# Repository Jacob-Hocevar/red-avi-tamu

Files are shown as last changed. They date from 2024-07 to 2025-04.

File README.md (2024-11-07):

# TAMU RED Avionics and Controls

This repository is home to the code and documentation for the Avionics and Controls subteam of the Texas A&M University Rocket Engine Design (<a href="https://www.tamured.space/">TAMU RED</a>) team.

## Organization

This repository is organized at the highest level by campaign. The current testing campaign is Elysium and all current code-related projects are found within. All previous campaigns are located within the Archive directory.

This repository is managed by <a href="https://github.com/Jacob-Hocevar">Jacob Hocevar</a>.

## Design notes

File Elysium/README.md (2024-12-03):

# Elysium
## Elysium GUI
The Elysium Graphical User Interface is the primary way that the system is controlled. It handels the inputs of the operator, automated control sequences, as well as the live display, graphing, and storage of data. It is programmed in C++ with Qt. For information on how to run and recompile (as needed), see the README.md in that directory.

## Real_Teensy
This directory contains the sketch(es) used by the Teensy to interpret the signals from the GUI, directly send the signals to actuate the valves, and read/transmit data from the sensors. Additionally, the system will handle an abort if there is a communications failure.

## Virtual_Teensy
This directory contains the code for a simulated version of the Teensy which is used to test the GUI. It recognizes and prints out any commands it recieves, and allows a user to control the data that it outputs to the GUI. For information on how to run and recompile (as needed), see the README.md in that directory.

Additionally, it will be configured to connect to another real Teensy to allow for Hardware In-the-Loop (HIL) testing.

## Data Formatting
For Elysium, all data will be transferred in `key:value` pairs. These pairs can be chained together in a comma separated string `"key1:val1,key2:val2,key3:val3\r\n"`, which terminates the carriage return (`'\r'`) and newline (`'\n'`) characters (the standard ending protocol for serial communication).The three goals are standardization, ease of maintainence/extension, and redundancy.

Standardization is both across programs and across subteams. We shall use the IDs of Sensors and Valves from the cross-team P&ID as the `key` terms, and the relevant data as the `value` terms. This will eliminate confusion between groups that were experienced in the WTS campaign, when one team was using `P1` and `P2`, and the other was using `PA` and `PB`.

This makes maintainence easier because it allows sensors and valves to be universally configured with a single, critical value. Similarly, if more valves or sensors are added, they can be added to the system with the same, single value.

This allows for some redundancy in the data transmission. If one value or part of a value fails to send correctly, the rest of the data in that batch (because of the keys), can still be readily and accurately identified by the receiver.

### Comparison to Older Design
Compare to the simpler system used during the WTS campaign: Comma separated values where the position dictates which property it corresponds to. First, the order of the properties had to be explicitly coordinated between the Teensy group and the GUI group and was not in reference to an existing, agreed upon document (such as the P&ID). Second, if a new sensor was added, both sides had to again determine where in the sequence to put the new value and manually hard-code it. Finally, if one value fails to send, all the following values (in that batch) are shifted and thus misread by the system.

### Example
Suppose the P&ID has three Pressure Transduces (P1-P3), two Thermocouples (T1 and T2) and one accelerometer (A1), which reads accelerations in three directions. The Teensy also outputs the local time with key `t`. Thus, it should output something like:

`"t:6545450000,P1:685.5422001,P2:14.78512405,P3:500.12124541,T1:7.2301502,T2:312.128575954,A1x:0.784213850,A1y:0.34517850652,A1z:2.0006781249\r\n"`

The order of the pairs does not matter, so something like the following is also acceptable, though less readable for debugging:

`"P3:500.12124541,A1x:0.784213850,P1:685.5422001,T2:312.128575954,A1z:2.0006781249,P2:14.78512405,T1:7.2301502,t:6545450000,A1y:0.34517850652\r\n"`

### Valve Example
For the valves, the solution is nearly identical, except that each command is always sent on its own line (no comma separated strings). Additionally, the value `0` always denotes a closed valve or close operation, and the value `1` always denotes an open valve or operation. For any extra electrical components (such as the ignition system), `0` will correspond to no power and `1` will correspond to providing power.

Consider a system with four normally closed solenoid valves (NCS1-NCS4) and two linearly-actuated ball valves (LA-BV 1 and LA-BV 2), and an igniter (IG1).

The signals to close all solenoids, open all ball valves and power igniter #1 would be given by:

`"NCS1:0\r\n"`
`"NCS2:0\r\n"`
`"NCS3:0\r\n"`
`"NCS4:0\r\n"`
`"LA-BV 1:1\r\n"`
`"LA-BV 2:1\r\n"`
`"IG1:1\r\n"`

Spaces in the IDs do not affect anything in either system. Again, these could be given in any order.

## Known Issues
There are a couple issues which have evaded all attempts to remove, but have simple methods to circumvent.

### GUI Freezes when connecting to Teensy
Identify: This typically results in the GUI freezing for several seconds, then expanding to full size, but not detecting any data inbound. It also will freeze upon shutdown or disconnect.

Cause: The connection to the Teensy is really sensitive with repeated connections and disconnections, especially with the WSL forwarding.

Solution: Unplug/replug the Teensy, and immediately attach it to WSL and attempt the connection again.<br>
A similar fix is to detach from WSL, and open the serial monitor in the Arduino IDE. Try opening and closing the serial monitor menu, and it should alternate between correct functionality, and a blank screen. When it is on a blank screen, close it, attach to WSL and attempt the connection again.

### GUI Connects, but the Teensy stays in the aborted state
Identify: GUI immediately "connects", but all data fields remain blank and the terminal is filled with `Not enough data: Aborted` and `Not enough data: New Input= nop`.

Cause: The connection to the Teensy is really sensitive and the first data sent over the connection often is lost/corrupted (buffer overriden?). This only occurs the first time after the Teensy is restarted.

Solution: Close the GUI and relaunch it. Not totally sure why, but it only ever happens the first time.

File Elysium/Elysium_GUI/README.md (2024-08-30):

# How to start the GUI

First navigate so that your active directory is `Elysium_GUI`.

If you have made no changes/it is already compiled, simply run `sudo ./Elysium_GUI`.

If you have just changed a couple files, but not added significant includes or new files:
1. `make` to compile.
2. `sudo ./Elysium_GUI` to run.

If you have made signficant changes (new files or substantive includes):
1. `qmake -project` to (re)create the project file.
2. Update the project file:

    A. Set `INCLUDEPATH = ./Headers` so it can locate the header files.

    To let the makefile/compiler know where to find core includes:

    B. Add a line reading `QT += widgets` for QApplication and QMainWindow, among others.

    C. Add a line reading `QT += gui` for QPixmap.

    D. Add a line reading `QT += core` for the namespace (alignment flags, among others).

    E. Add a line reading `QT += serialport` for the serial connections.

    [comment]: # (Update Here if new lines become necessary)

3. `qmake Elysium_GUI.pro` to generate a makefile from the project file.
4. `make` to compile (this is where errors will show up with improper code).
5. `sudo ./Elysium_GUI` to run.

## Setup
Use a unix-like enviornment and install the proper libraries.

In my case, the command is `sudo apt install make` to install `make`.

You will need the `g++` compiler and the access to the commands `make` and `qmake` (via `qtchooser` library), and `qtdeclarative5-dev`.

Additionally, for the serial comunication, I installed `libqt5serialport5-dev`, and for the live graphs, I installed `libqt5charts5-dev`.

## To connect to the Teensy via WSL
1. Install `usbipd-win` via the .msi file for the latest release https://github.com/dorssel/usbipd-win/releases.
2. Open Windows Powershell as administrator and execute `usbipd list`.
3. Identify which device corresponds to the Teensy (the description may not list it, so confirm the COM number via the Arduino IDE or any other method) and remember the bus ID.
4. Execute `usbipd bind --busid ID` (with the previously found `ID`). Verify that it is shared with `usbipd list`, if desired.
5. Execute `usbipd attach --wsl --busid ID` (with the previously found `ID`). Verify that it is attached with `usbipd list`, if desired.
6. A more precise way to verify is to open WSL terminal and execute `lsusb`, which should list the attached port.

To detach, either remove the device physically or execute `usbipd detach --busid ID` (with the previously found `ID`).

Every time the device is disconnected or the PC restarts, you will have to repeat step 5 (although, it would be wise to recheck the list to confirm the `ID`).

## Additional Note
The `sudo` keyword is needed for running the executable in order to access the serial ports. You will recieve a `PermissionError` without it. I am not certain why this is, but I think the `/dev/` directory (which is how ports are treated in WSL) is considered protected.

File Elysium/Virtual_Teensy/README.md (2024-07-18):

# How to use the Virtual Teensy
## Setup

Install the socat module with `sudo apt-get install socat`.

## Usage

Open two WSL terminals. In first, it does not matter what directory is open.

Execute `sudo socat -d -d pty,raw,echo=0,b115200,link="/dev/Test_GUI" pty,raw,echo=0,b115200,link="/dev/Virtual_Teensy"`. This will generate a pair of `/dev/pts/X` serial ports with arbitrary values `X` (typically, 0, 1, or 2, but can vary based on system activity), which are linked to the fixed names `/dev/Test_GUI` and `/dev/Virtual_Teensy`. This command needs to remain active as long as you need to test the GUI/Virtual Teensy.

In the second terminal, navigate so that your active directory is `Virtual_Teensy`.

First navigate so that your active directory is `Virtual Teensy`. Execute `make` any time you update a source file. To run the Virtual Teensy, execute `sudo ./Virtual_Teensy`.

## Additional Testing
If the Virtual Teensy is not working (or for some other reason you want to check that the virtual ports are working), you can manually send information to and recieve from the pair of ports via the following commands.

`sudo bash -c 'echo "hello" > /dev/Test_GUI'` to write a signal. This command uses strange formatting because both the `echo` part and accessing the port (which is treated as a file) require the root privileges, but a typical `sudo echo "hello" > /dev/Test_GUI` would only give root privileges to the `echo` portion.

`sudo cat /dev/Virtual_Teensy` to recieve a signal. This command will "listen in" to the port until you exit the command.

You can swap the names as desired. Remember that only one application can be attached to each port at the same time, so if the Virtual Teensy is running, you can only connect to `/dev/Test_GUI` and vice versa if the GUI is connected.

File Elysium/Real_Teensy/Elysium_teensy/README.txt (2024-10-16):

Elysium Teensy
Overview
The Elysium Teensy program is designed for managing and monitoring various sensors and actuators in a complex system. It integrates load cells, thermocouples, pressure transducers, and accelerometers to provide real-time data and control mechanisms for a hardware project, possibly in an experimental or industrial setup. This README will guide you through downloading the necessary libraries from GitHub and installing them into your Arduino library folder.

Features
- Sensor Management: Continuously reads and processes data from pressure transducers, load cells, thermocouples, and accelerometers.
- Actuator Control: Controls multiple solenoid valves and other actuators based on user input.
- Data Logging: Sends sensor data to the serial monitor for real-time monitoring.

Before installing the libraries, ensure you have the Arduino IDE installed on your computer.

To run the Elysium Teensy program, you need the following libraries:
- HX711 - For interfacing with load cells.
- Adafruit MCP9600 - For thermocouple readings.
- Wire - For I2C communication (included with the Arduino IDE).
- IMU - For accelerometer readings.
- LSM6DSL and LIS3MDL - For accelerometer hardware interfacing.

Downloading Libraries:

For the Adafruit MCP9600 library, download it through the Arduino IDE library search and downloader.

For the HX711, IMU, LSM6DSL and LIS3MDL libraries, follow the process listed below:
1. Go to the RED GitHub repository.
2. Click on the "download raw file content" button for all 4 of the above-listed libraries. Do this for both the .h and .cpp files when available.
3. Create folders for these files, named with the library name (do not include the .h or .cpp). Move the downloaded content files into these folders.
4. Locate Your Arduino Library Folder:
	Open Arduino IDE.
	Go to File > Preferences.
	In the preferences window, note the location of the "Sketchbook location". The libraries folder is located inside this directory.
5. Copy the Library Files:
	For each downloaded library, locate the folder.
	Copy the entire folder for each library (e.g., HX711, Adafruit_MCP9600, etc.).
	Paste these folders into your Arduino libraries directory (e.g., Documents/Arduino/libraries).
6. Restart Arduino IDE:
	After copying the libraries, restart the Arduino IDE to ensure it recognizes the new libraries.

User Inputs:
Be sure to set the following user-defined inputs according to your specific hardware setup:

- Sensor update interval
- Shutdown time
- Pin assignments for valves, load cells, and pressure transducers
- Compiling and Uploading
- Connect your Teensy board to your computer via USB.
- In Arduino IDE, select the correct board and port:
- Go to Tools > Board and select your Teensy model.
- Go to Tools > Port and select the port corresponding to your Teensy board.
- Click on the checkmark to compile the code, and if successful, click on the right arrow to upload it to your board.

Conclusion:
You are now ready to use the Elysium Teensy program.

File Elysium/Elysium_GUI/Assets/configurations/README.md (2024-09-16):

# Configurations
Each subdirectory represents a configuration of valves and sensors, with the corresponding P&ID. The name of the subdirectory indicates the configuration name, the file names within are required to be fixed so that the GUI can access them. I.e., there must files titled `sensors.cfg`, `valves.cfg`, `control_states.cfg` and `P&ID.png`.

## Format of configuration files

Each row (or possibly pair of rows) represents one element that should be added to the GUI. Every row is a set of comma seperated values (no additional spaces) representing a set of arguments.

The first arguments identify the object and provide the parameters required for its initialization. The final arguments, which may go on the second row&mdash;this has not been implemented yet&mdash;will indicate additional placement info to the GUI. For example, should the sensor be independent or grouped with the Pressure Sensors or where on the P&ID should it be located.

The order matters, as the elements are added to the GUI from the top down, starting at the beginning of the file.

### For `sensors.cfg` the arguments are given in the following order:
`ID,name,unit`$\newline$
`group,type`

The first line is self explanatory; `group` indicates that the sensor should be placed in the GUI in a seperated area for all sensors in that group, titled with `group`. The ordering is still first is top, and the same applies to the groups (first group top left, then top right, the second row left, second row right, etc.). If it is left blank (i.e., the line line starts with a `,`), then it is grouped but without a title. The `type` indicates if the sensor is a directly measured quanitity (`measured`), or derived from the others (`derived`). Additional `derived` quantities will require modifying GUI_DAQ_Window(.h/.cpp) to handle their calculations.

### For `valves.cfg` the arguments are given in the following order:
`class,ID,name,[args]*`

The `class` has three values: `Valve`, `Solenoid`, and `LA_Ball`, indicating the `Valve`, `Solenoid_Valve`, and `LA_Ball_Valve` classes respectively.

The `[args]*` depends on the class. For `Valve` it indicates the `state` parameter, for `Solenoid` it indicates the `normally_open` parameter, and for `LA_Ball` it will be two values indicating `state` then `is_open`.

### For `control_states.cfg` the arguments are given in the following order:
`name1/name2/name3,row1/row2/row3,col1/col2/col3`$\newline$
`valve1:state1,valve2:state2,valve3:state3`

Note that while this example lists three (3) of all values, the lists can be shortened or lengthed at will for arbitrary control.

The first line indicates all names of the control state in a `/` separated list, followed by the rows and then columns that each name should be displayed on, similarly presented in a `/` separated list. This allows for multiple named states to have the same valve configurations and be listed in the correct places in the operations page.

The second line indicates the states of all valves in a comma separated list of key:value pairs, denoting the valves (by ID) and the state (0=closed, 1=open). The ignition system is also treated as a valve with ID=IGNITE and 0=unpowered, 1=powered. Additionally, the requirement that there are no personnel near the engine is listed as a valve with ID=SAFE and 0=personnel can be nearby, 1=operator must confirm that no personnel are nearby.

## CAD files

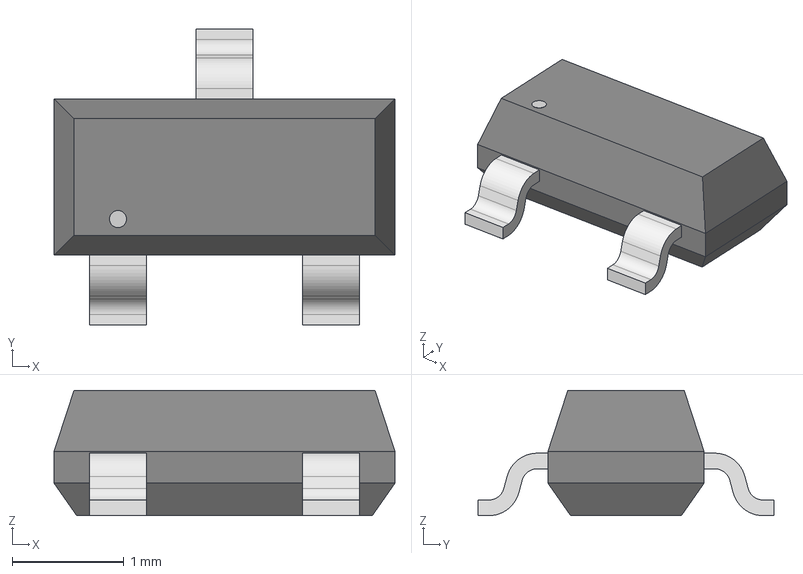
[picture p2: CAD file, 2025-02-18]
Elysium/GIGAPCB/GIGAPCB KiCAD Library/3D Models/BJT_SMMBT4403LT1G.step
3.05 x 2.64 x 1.12 mm

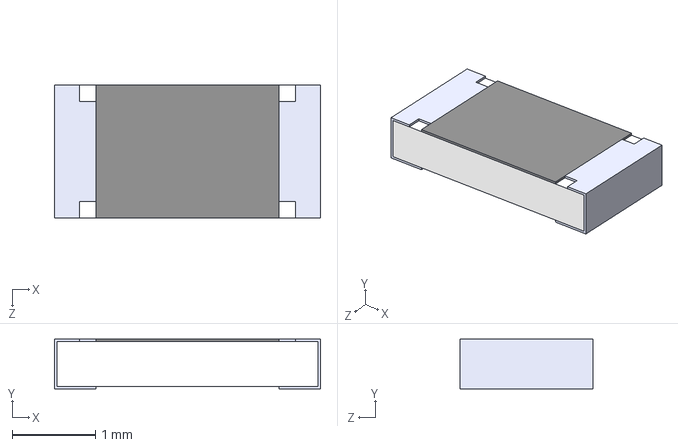
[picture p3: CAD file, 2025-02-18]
Elysium/GIGAPCB/GIGAPCB KiCAD Library/3D Models/Generic 2106 Resistor.step
3.20 x 0.6 x 1.60 mm

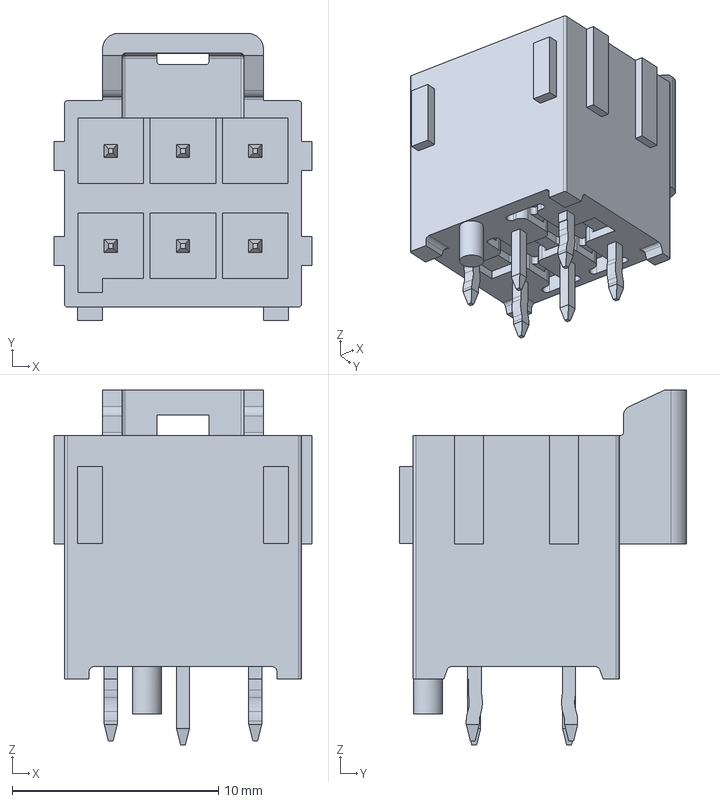
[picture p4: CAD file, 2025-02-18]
Elysium/GIGAPCB/GIGAPCB KiCAD Library/3D Models/CONN_1722981206_Universal.step
12.5 x 13.9 x 17.2 mm

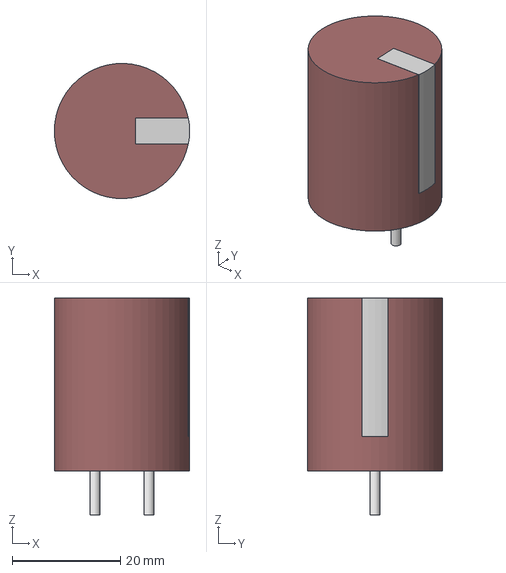
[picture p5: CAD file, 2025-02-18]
Elysium/GIGAPCB/GIGAPCB KiCAD Library/3D Models/CP_LGW2D561MELA30.step
25.0 x 25.0 x 40.1 mm

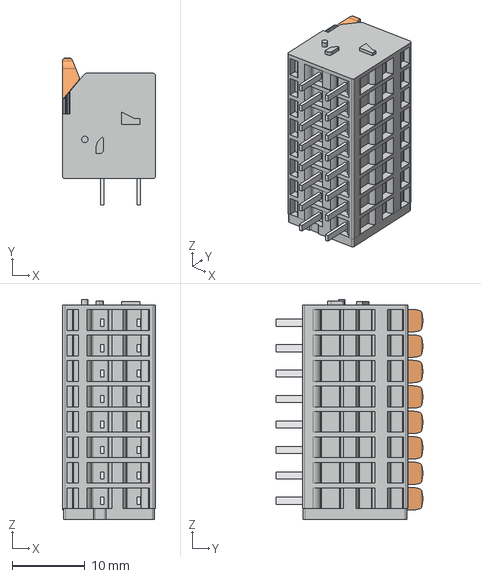
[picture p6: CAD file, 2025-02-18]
Elysium/GIGAPCB/GIGAPCB KiCAD Library/3D Models/CONN_2601_3108.stp
12.8 x 20.2 x 30.2 mm

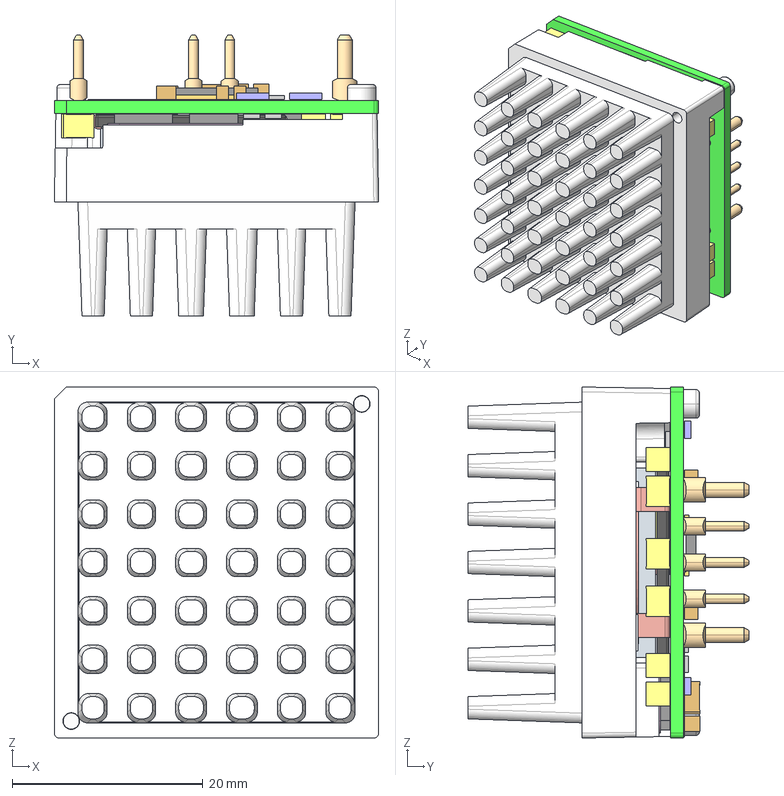
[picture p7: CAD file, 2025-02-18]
Elysium/GIGAPCB/GIGAPCB KiCAD Library/3D Models/DCC_I7C4W008A120V_PF3_R.step
34.0 x 29.5 x 36.8 mm
I7C_PWB
ZP00206_01 x 2
ZP00232_01 x 8
1206_CAP_COLOR x 3
1206_RLP32 x 4
0805_CAP_COLOR x 4
TSSOP28_BLOCK_01
1210_CAP_2R5MM x 9
0805_RES
5X6X1FET_BLOCK x 4
ERU19_FERRITE
ERU19_WIND
EUR_19_LEG1
EUR_19_LEG2
EUR_19_BASE
EUR_19_LEG3
AP00029
1206_RES_COLOR x 2
GAP-FILLER-BLOCK8 x 2
GAP-FILLER-BLOCK4
ZP00309_MP_00
ZP00264_SIMPLE x 2

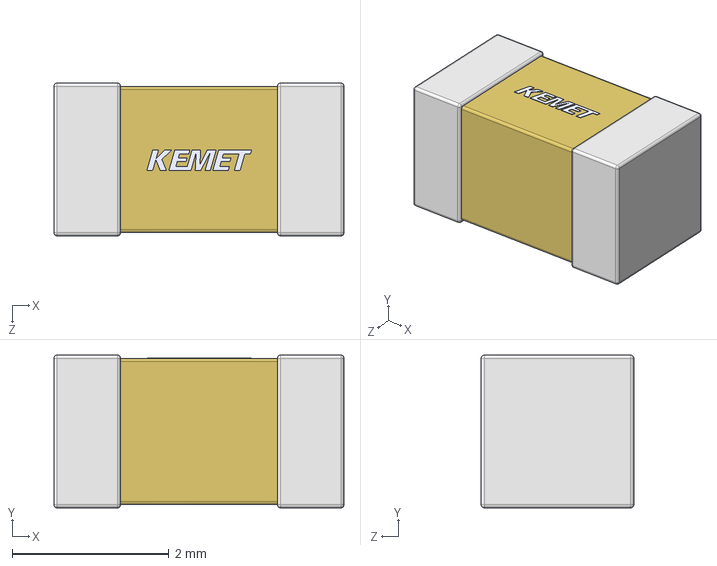
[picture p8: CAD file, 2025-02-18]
Elysium/GIGAPCB/GIGAPCB KiCAD Library/3D Models/Generic 2106 Capacitor-LAPTOP-A93BNMFG.step
3.70 x 1.95 x 1.95 mm

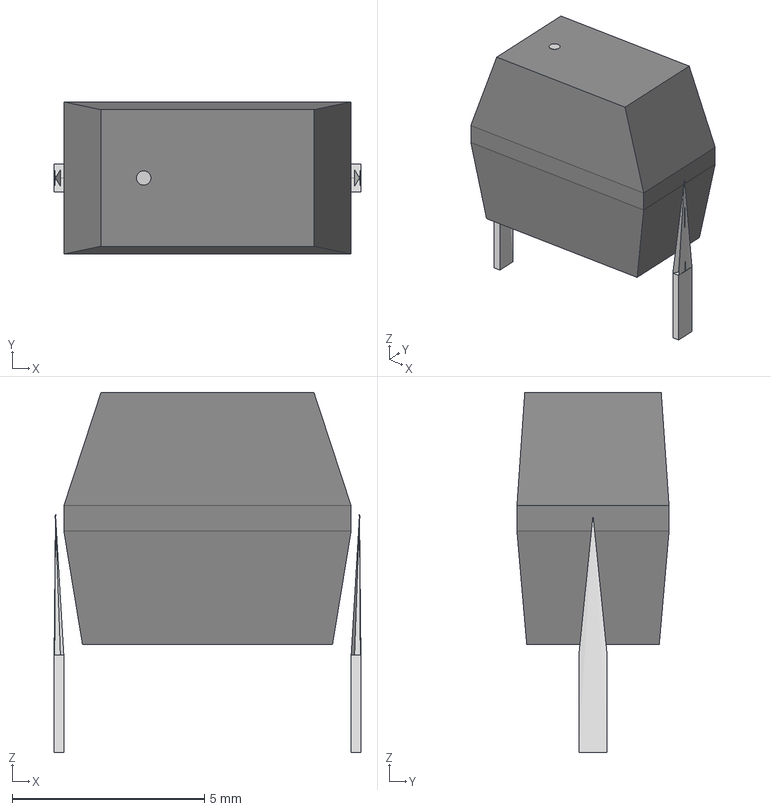
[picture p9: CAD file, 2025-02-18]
Elysium/GIGAPCB/GIGAPCB KiCAD Library/3D Models/DIP_DS01-254-L-01BE.step
7.99 x 3.96 x 9.38 mm

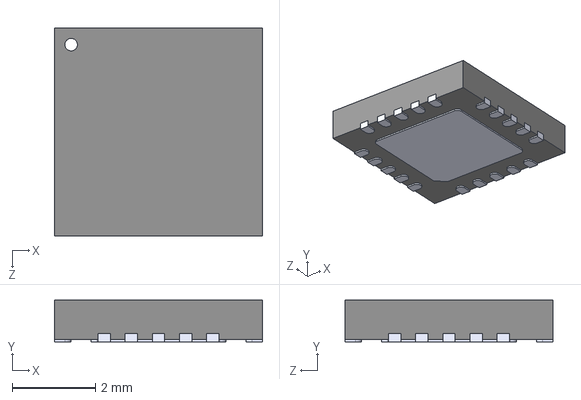
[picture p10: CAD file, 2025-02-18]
Elysium/GIGAPCB/GIGAPCB KiCAD Library/3D Models/IC_MCP9600-E_MX.step
5.00 x 1.00 x 5.00 mm

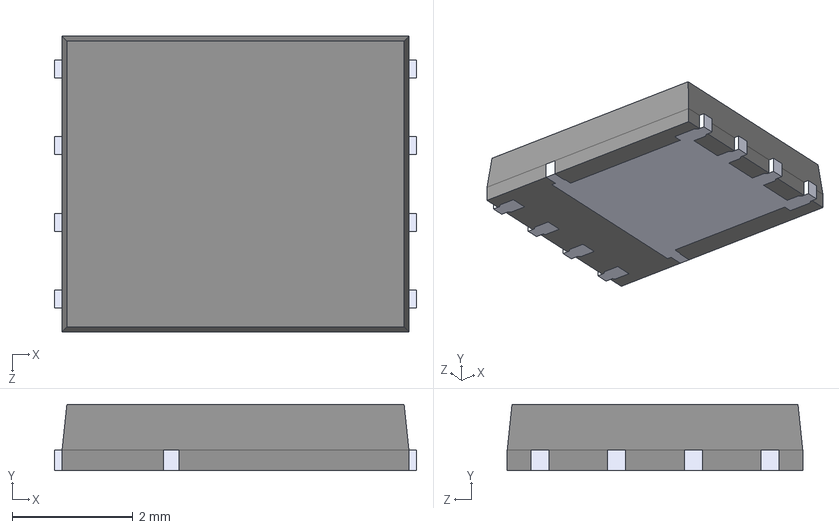
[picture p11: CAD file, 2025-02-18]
Elysium/GIGAPCB/GIGAPCB KiCAD Library/3D Models/MOSFET_CSD17306Q5A.step
6.00 x 1.10 x 4.90 mm

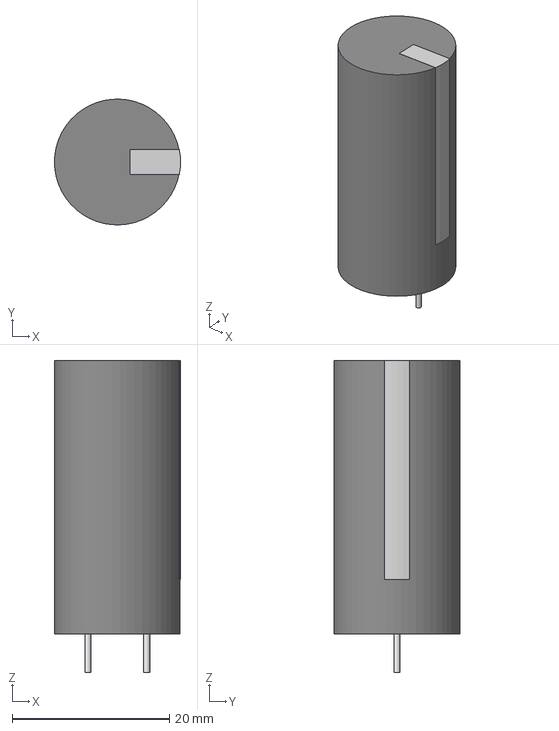
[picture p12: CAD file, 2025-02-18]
Elysium/GIGAPCB/GIGAPCB KiCAD Library/3D Models/CP_EGPA101ELL471ML35S.step
16.0 x 16.0 x 39.7 mm

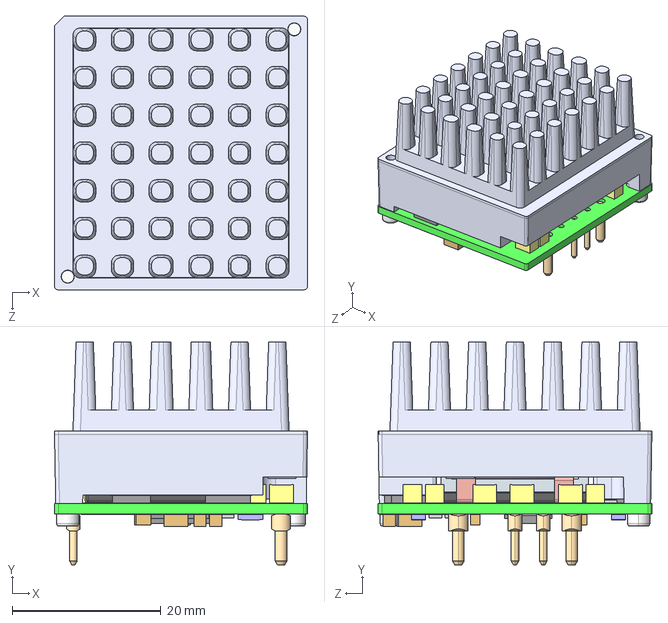
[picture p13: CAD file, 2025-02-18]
Elysium/GIGAPCB/GIGAPCB KiCAD Library/3D Models/DCC_I7C4W012A050V-0F1-R.step
34.0 x 30.0 x 36.8 mm

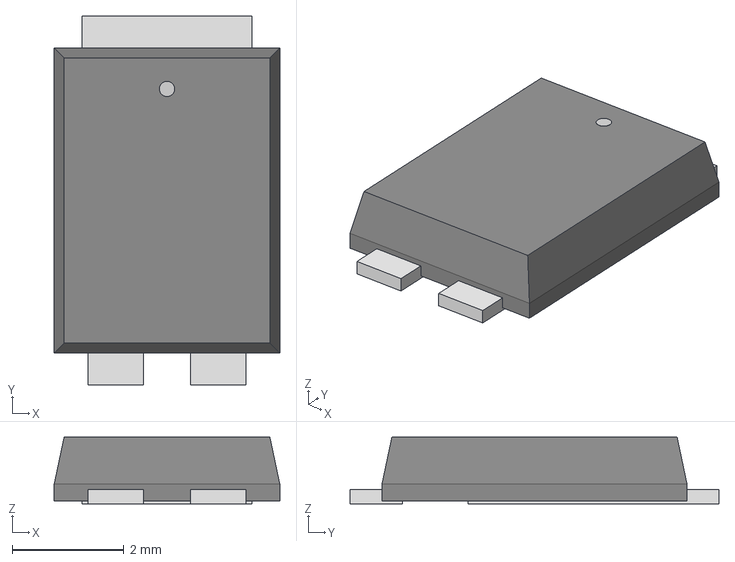
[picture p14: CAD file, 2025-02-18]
Elysium/GIGAPCB/GIGAPCB KiCAD Library/3D Models/D_PDS760_13.step
4.04 x 6.60 x 1.20 mm

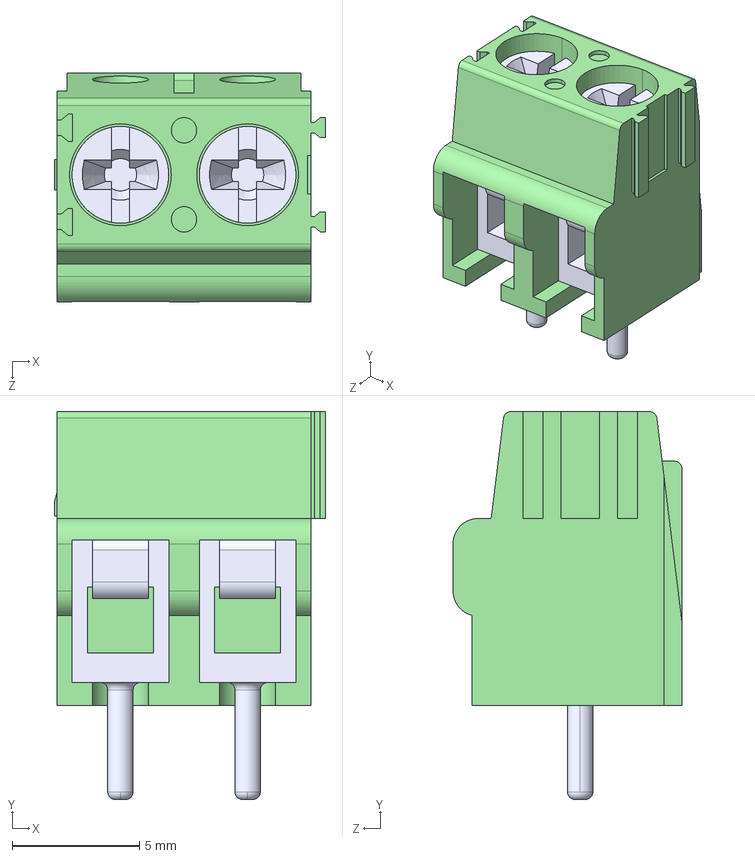
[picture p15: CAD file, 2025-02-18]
Elysium/GIGAPCB/GIGAPCB KiCAD Library/3D Models/CONN_1935161.step
10.7 x 15.2 x 9.00 mm

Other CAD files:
Elysium/GIGAPCB/GIGAPCB KiCAD Library/3D Models/CONN_5-2301995-2_RJ45.stp
Elysium/GIGAPCB/GIGAPCB KiCAD Library/3D Models/C_KRM55WR72A226MH01L.step
Elysium/GIGAPCB/GIGAPCB KiCAD Library/3D Models/CONN_1722981104_Universal.step
Elysium/GIGAPCB/GIGAPCB KiCAD Library/3D Models/CONN_1722981108_Universal.stp
Elysium/GIGAPCB/GIGAPCB KiCAD Library/3D Models/CONN_2601_3110.stp
Elysium/GIGAPCB/GIGAPCB KiCAD Library/3D Models/CP_UBY1K471MHL.step
Elysium/GIGAPCB/GIGAPCB KiCAD Library/3D Models/CP_UCS2C331MHD.step
Elysium/GIGAPCB/GIGAPCB KiCAD Library/3D Models/CP_UCZ2A301MNQ1MS.step
Elysium/GIGAPCB/GIGAPCB KiCAD Library/3D Models/DCC_I7C4W012A050V-003-R.step
Elysium/GIGAPCB/GIGAPCB KiCAD Library/3D Models/IC_TCA9548APWR.stp

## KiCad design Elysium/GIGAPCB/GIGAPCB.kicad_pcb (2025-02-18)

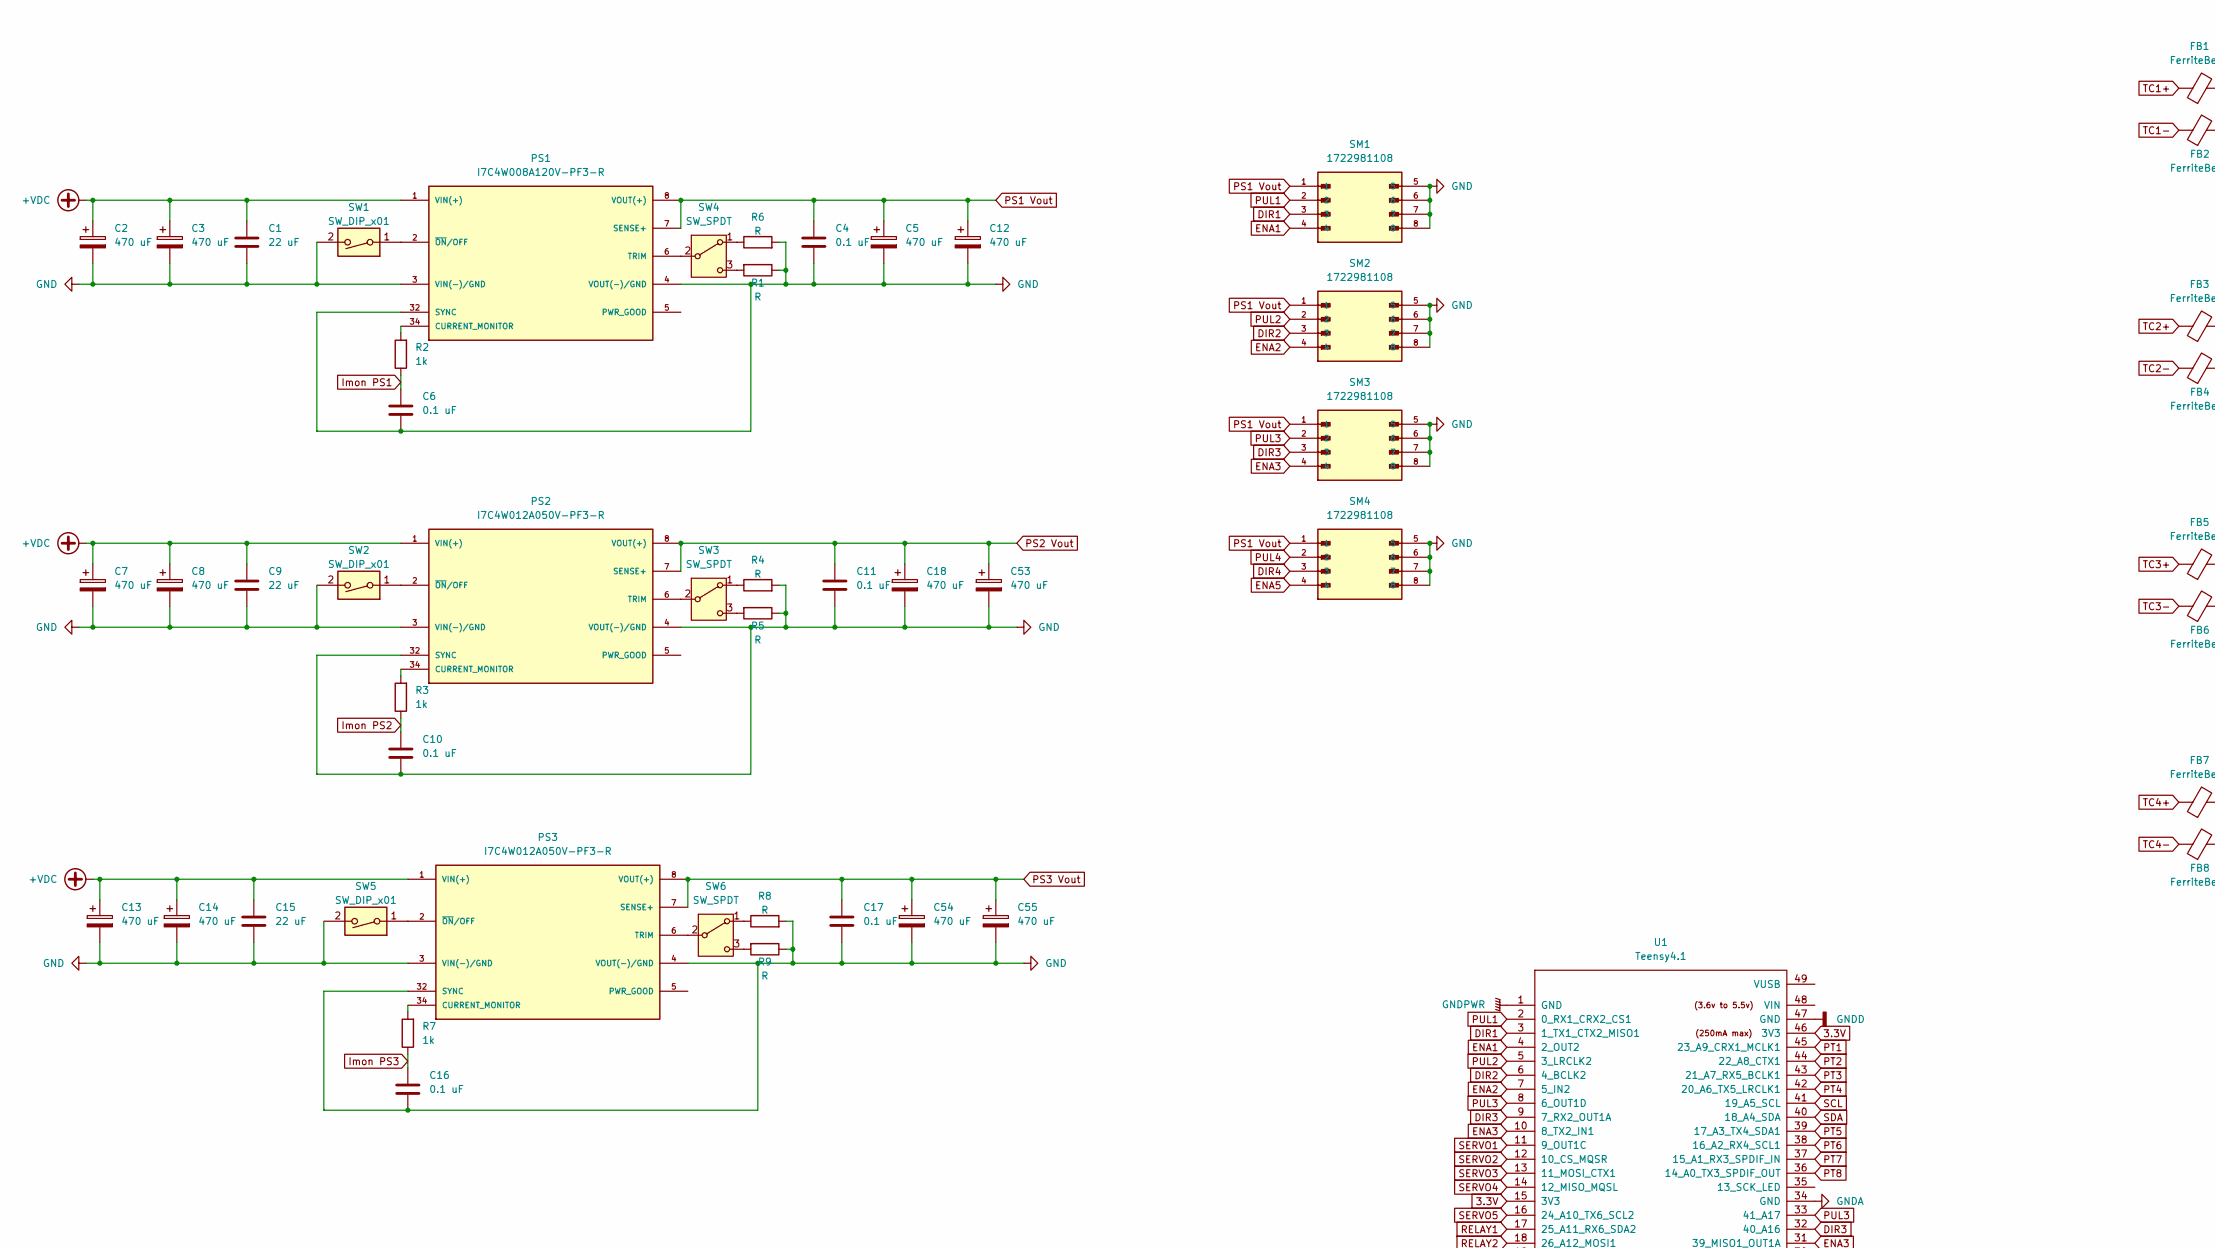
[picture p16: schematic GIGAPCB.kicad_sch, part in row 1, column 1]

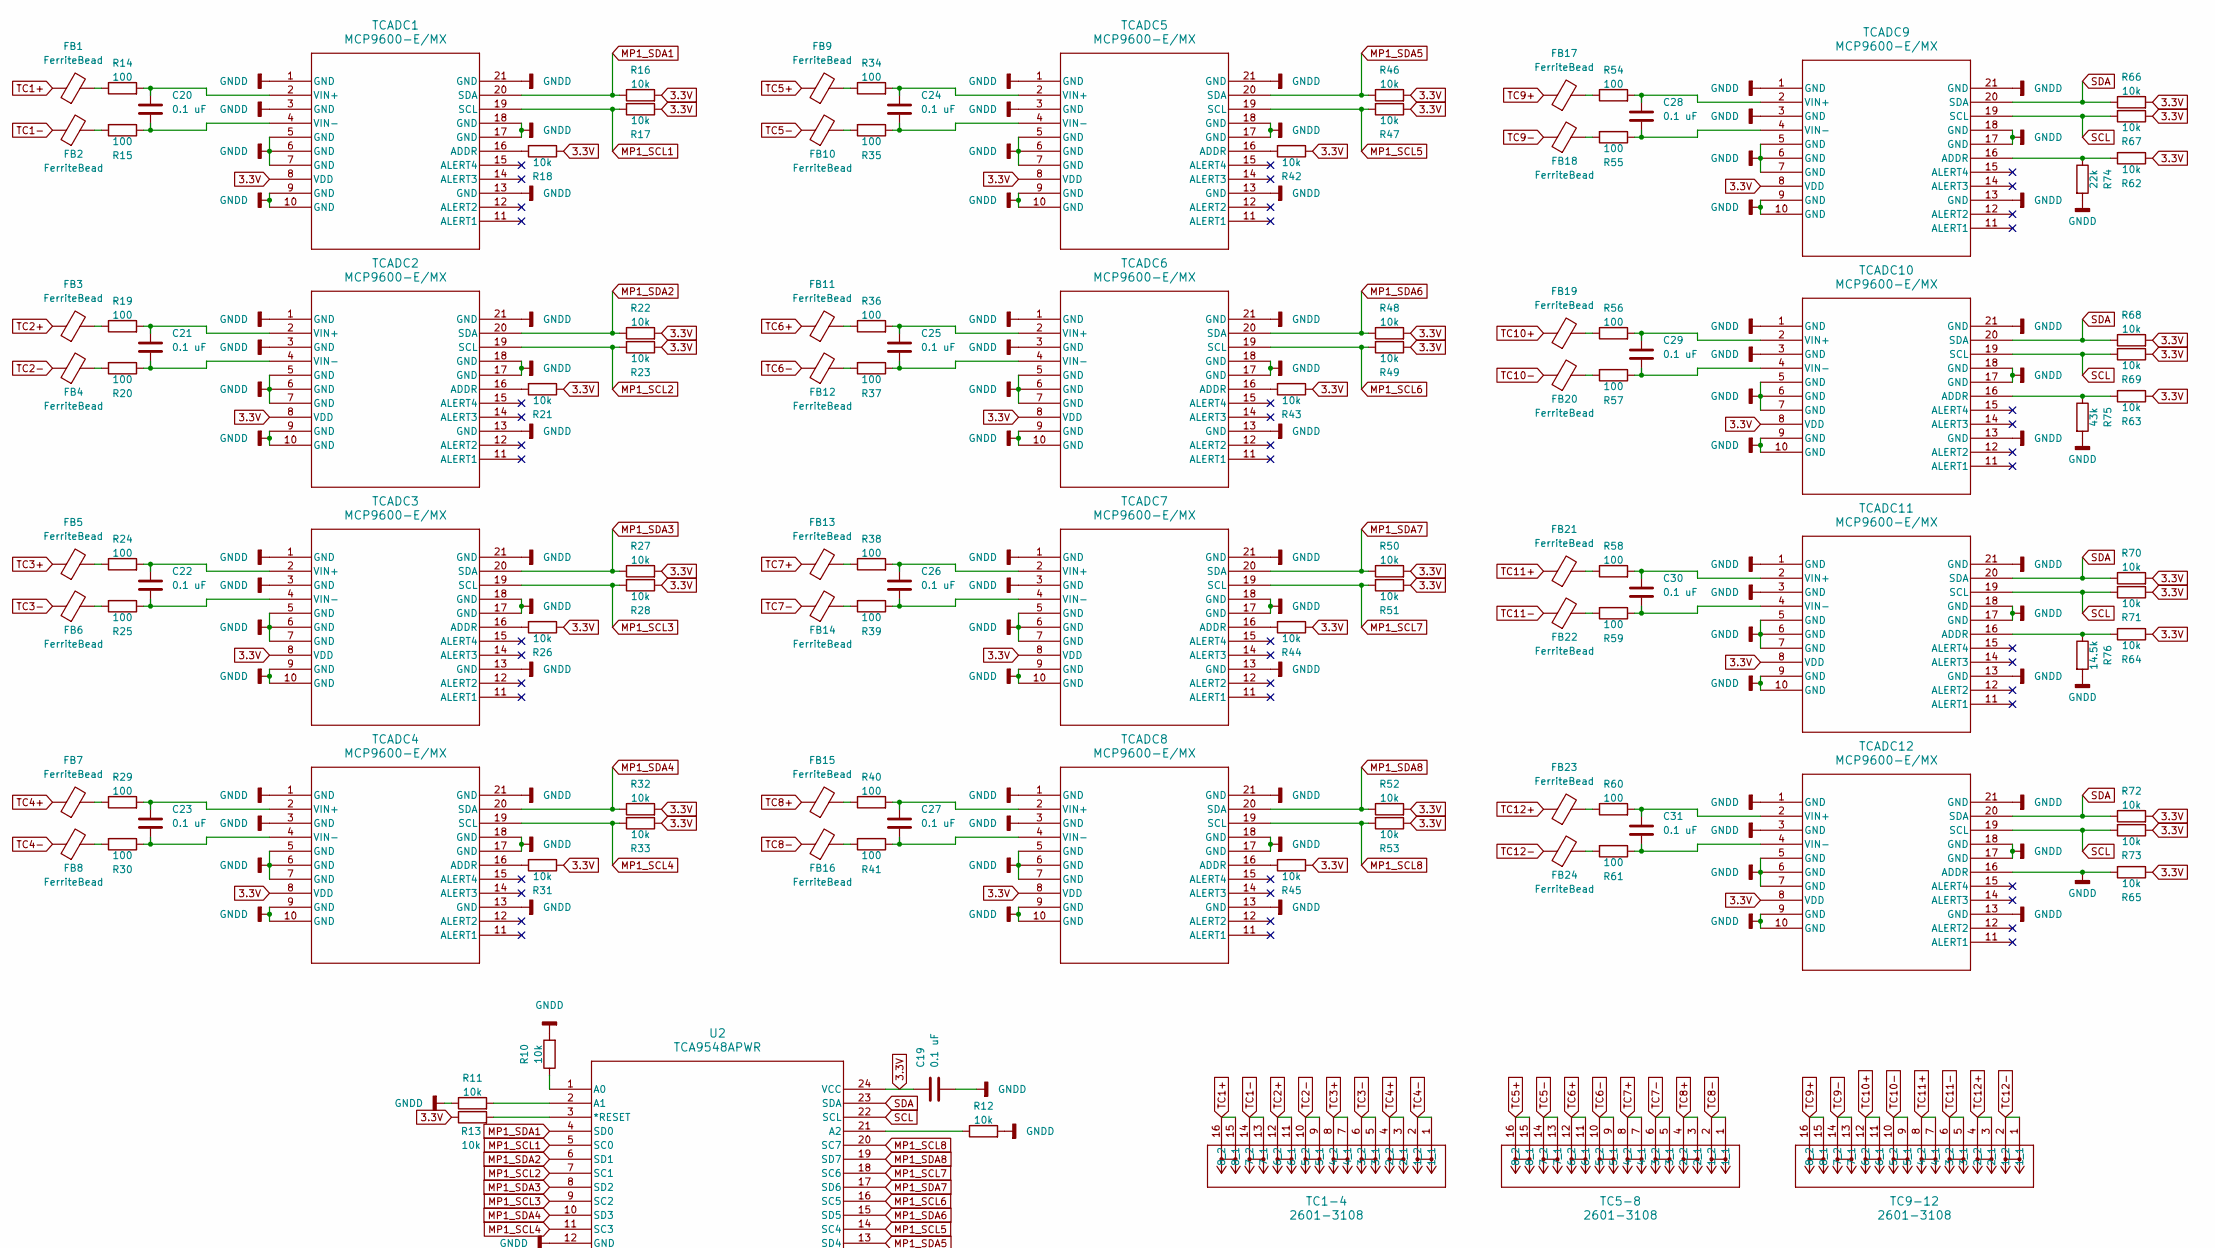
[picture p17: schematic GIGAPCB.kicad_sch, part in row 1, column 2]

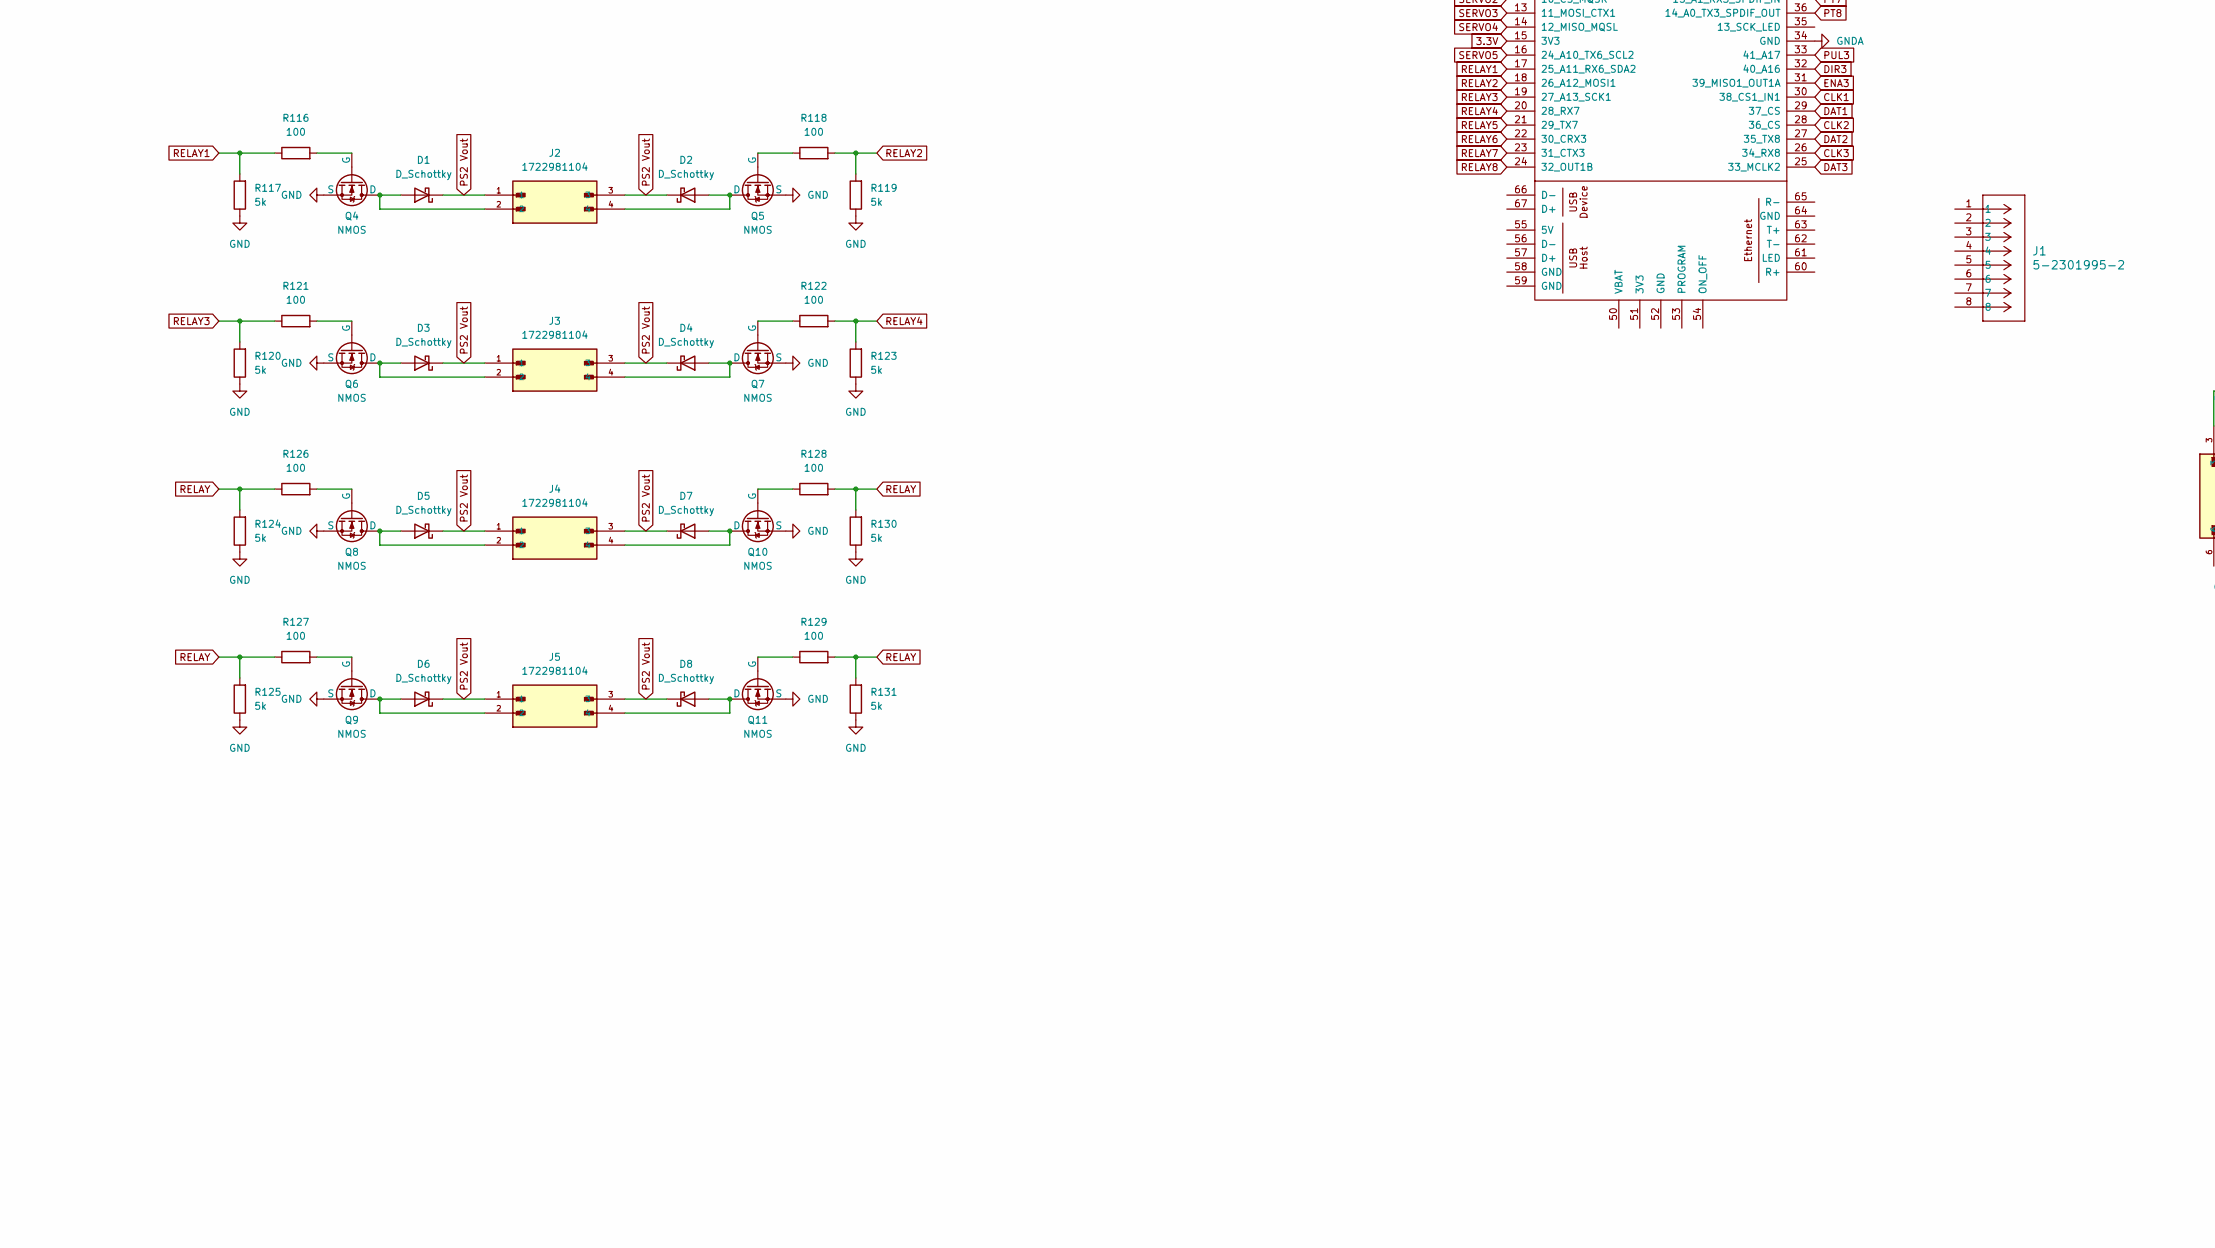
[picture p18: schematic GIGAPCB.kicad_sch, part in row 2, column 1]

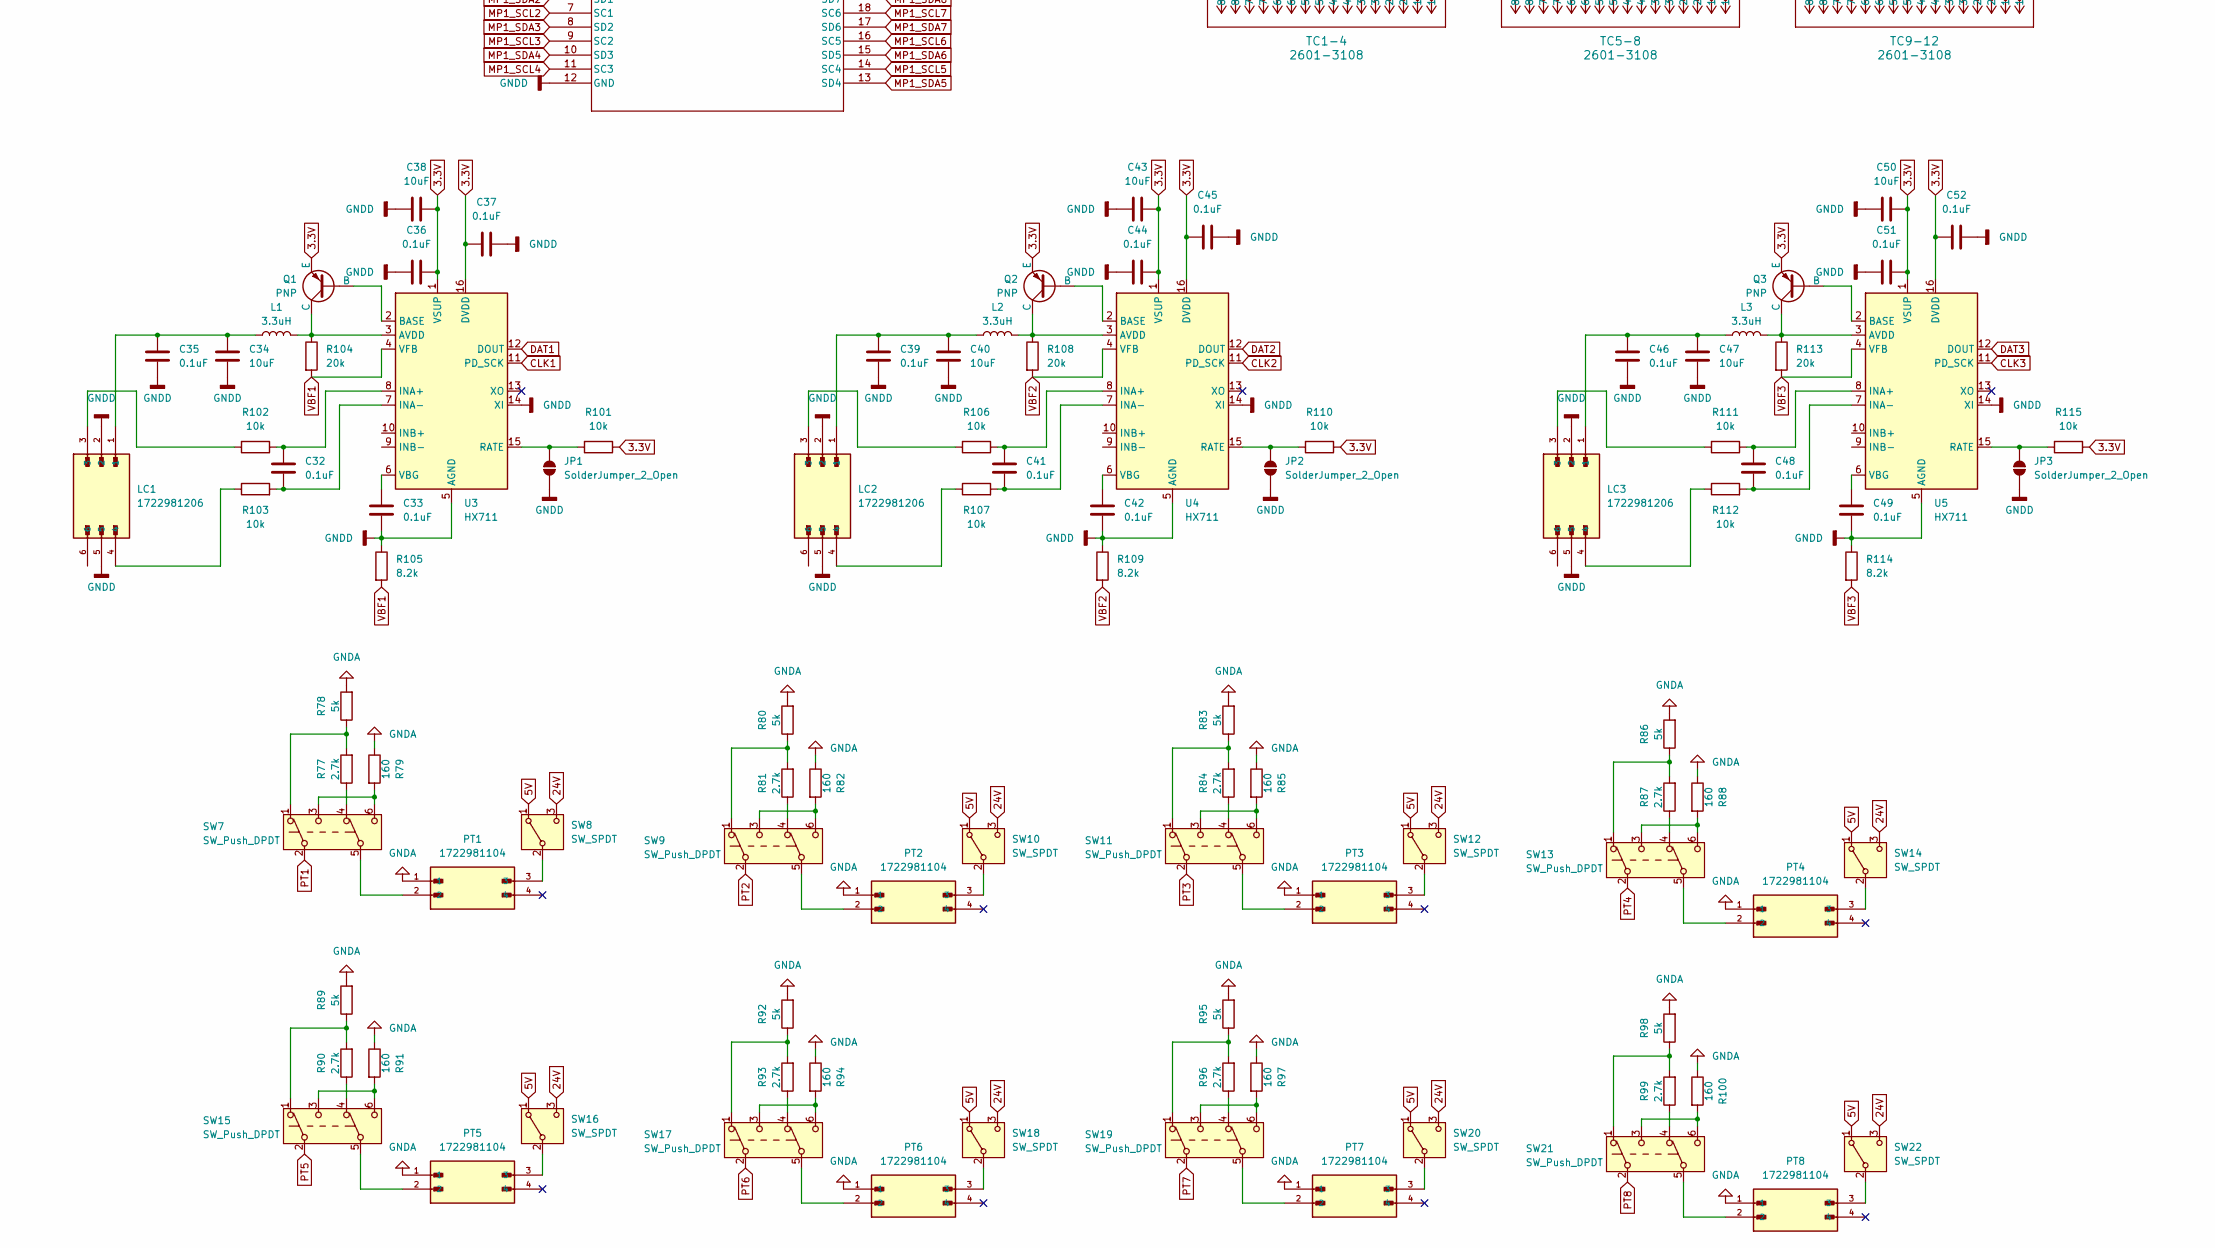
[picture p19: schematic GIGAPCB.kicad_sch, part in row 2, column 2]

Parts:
C1, C9, C15: 22 uF; C_KRM55WR72A226MH01L
C2, C3, C5, C7, C8, C12, C13, C14, C18, C53, C54, C55: 470 uF; CP_EGPA101ELL471ML35S
C4, C6, C10, C11, C16, C17, C19, C20, C21, C22, C23, C24, C25, C26, C27, C28, C29, C30, C31: 0.1 uF; C_0805_2012Metric
C32, C33, C35, C36, C37, C39, C41, C42, C44, C45, C46, C48, C49, C51, C52: 0.1uF; C_0805_2012Metric
C34, C38, C40, C43, C47, C50: 10uF; C_1206_3216Metric
D1, D2, D3, D4, D5, D6, D7, D8: D_Schottky; D_PDS760_13-M
FB1, FB2, FB3, FB4, FB5, FB6, FB7, FB8, FB9, FB10, FB11, FB12, FB13, FB14, FB15, FB16, FB17, FB18, FB19, FB20, FB21, FB22, FB23, FB24: FerriteBead; R_0805_2012Metric
J1: 5-2301995-2; RJ25_Wayconn_MJEA-660X1_Horizontal
J2, J3, J4, J5: 1722981104; CONN_1722981104; PARTREV C1
JP1, JP2, JP3: SolderJumper_2_Open; SolderJumper-2_P1.3mm_Bridged2Bar_Pad1.0x1.5mm
L1, L2, L3: 3.3uH; C_0805_2012Metric
LC1, LC2, LC3: 1722981206; CONN_1722981106; PARTREV C1
PS1: I7C4W008A120V-PF3-R; DCC_I7C4W012A050V_PF3_R; PARTREV V5
PS2, PS3: I7C4W012A050V-PF3-R; DCC_I7C4W012A050V_PF3_R; PARTREV V5
PT1, PT2, PT3, PT4, PT5, PT6, PT7, PT8: 1722981104; CONN_1722981104; PARTREV C1
Q1: PNP; PinSocket_1x03_P2.54mm_Vertical
Q2, Q3: PNP
Q4, Q5, Q6, Q7, Q8, Q9, Q10, Q11: NMOS; MOSFET_CSD17306Q5A
R1, R4, R5, R6, R8, R9: R
R2, R3, R7: 1k
R10, R11, R12, R13, R16, R17, R18, R21, R22, R23, R26, R27, R28, R31, R32, R33, R42, R43, R44, R45, R46, R47, R48, R49, R50, R51, R52, R53, R62, R63, R64, R65, R66, R67, R68, R69, R70, R71, R72, R73, R101, R102, R103, R106, R107, R110, R111, R112, R115: 10k; R_0805_2012Metric
R14, R15, R19, R20, R24, R25, R29, R30, R34, R35, R36, R37, R38, R39, R40, R41, R54, R55, R56, R57, R58, R59, R60, R61, R116, R118, R121, R122, R126, R127, R128, R129: 100; R_0805_2012Metric
R74: 22k; R_0805_2012Metric
R75: 43k; R_0805_2012Metric
R76: 14.5k; R_0805_2012Metric
R77, R81, R84, R87, R90, R93, R96, R99: 2.7k; R_1206_3216Metric
R78, R80, R83, R86, R89, R92, R95, R98, R117, R119, R120, R123, R124, R125, R130, R131: 5k; R_1206_3216Metric
R79, R82, R85, R88, R91, R94, R97, R100: 160; R_1206_3216Metric
R104, R108, R113: 20k; R_0805_2012Metric
R105, R109, R114: 8.2k; R_0805_2012Metric
SM1, SM2, SM3, SM4: 1722981108; CONN_1722981108; PARTREV C1; DigiKey_Part_Number WM11582-ND
SW1, SW2, SW5: SW_DIP_x01
SW3, SW4, SW6, SW8, SW10, SW12, SW14, SW16, SW18, SW20, SW22: SW_SPDT; PinSocket_1x03_P2.54mm_Vertical
SW7, SW9, SW11, SW13, SW15, SW17, SW19, SW21: SW_Push_DPDT
TC1-4, TC5-8, TC9-12: 2601-3108; CONN_2601_3108
TCADC1, TCADC2, TCADC3, TCADC4, TCADC5, TCADC6, TCADC7, TCADC8, TCADC9, TCADC10, TCADC11, TCADC12: MCP9600-E/MX; IC_MCP9600-EMX-M
U1: Teensy4.1; Teensy41
U2: TCA9548APWR; IC_TCA9548APWR-M
U3, U4, U5: HX711; SOP-16_3.9x9.9mm_P1.27mm

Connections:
3.3V: C19.1, C36.2, C37.1, C38.2, C43.2, C44.2, C45.1, C50.2, C51.2, C52.1, Q1.3 (E), Q2.3 (E), Q3.3 (E), R13.1, R16.2, R17.1, R18.1, R21.1, R22.2, R23.1, R26.1, R27.2, R28.1, R31.1, R32.2, R33.1, R42.1, R43.1, R44.1, R45.1, R46.2, R47.1, R48.2, R49.1, R50.2, R51.1, R52.2, R53.1, R62.1, R63.1, R64.1, R65.1, R66.2, R67.1, R68.2, R69.1, R70.2, R71.1, R72.2, R73.1, R101.1, R110.1, R115.1, TCADC1.8 (VDD), TCADC2.8 (VDD), TCADC3.8 (VDD), TCADC4.8 (VDD), TCADC5.8 (VDD), TCADC6.8 (VDD), TCADC7.8 (VDD), TCADC8.8 (VDD), TCADC9.8 (VDD), TCADC10.8 (VDD), TCADC11.8 (VDD), TCADC12.8 (VDD), U1.15 (3V3), U1.46 (3V3), U2.24 (VCC), U3.1 (VSUP), U3.16 (DVDD), U4.1 (VSUP), U4.16 (DVDD), U5.1 (VSUP), U5.16 (DVDD)
5V: SW8.1 (A), SW10.1 (A), SW12.1 (A), SW14.1 (A), SW16.1 (A), SW18.1 (A), SW20.1 (A), SW22.1 (A)
24V: SW8.3 (C), SW10.3 (C), SW12.3 (C), SW14.3 (C), SW16.3 (C), SW18.3 (C), SW20.3 (C), SW22.3 (C)
+VDC: C1.1, C2.1, C3.1, C7.1, C8.1, C9.1, C13.1, C14.1, C15.1, PS1.1 (VIN(+)), PS2.1 (VIN(+)), PS3.1 (VIN(+))
CLK1: U1.30 (38_CS1_IN1), U3.11 (PD_SCK)
CLK2: U1.28 (36_CS), U4.11 (PD_SCK)
CLK3: U1.26 (34_RX8), U5.11 (PD_SCK)
DAT1: U1.29 (37_CS), U3.12 (DOUT)
DAT2: U1.27 (35_TX8), U4.12 (DOUT)
DAT3: U1.25 (33_MCLK2), U5.12 (DOUT)
DIR1: SM1.3, U1.3 (1_TX1_CTX2_MISO1)
DIR2: SM2.3, U1.6 (4_BCLK2)
DIR3: SM3.3, U1.9 (7_RX2_OUT1A), U1.32 (40_A16)
DIR4: SM4.3
ENA1: SM1.4, U1.4 (2_OUT2)
ENA2: SM2.4, U1.7 (5_IN2)
ENA3: SM3.4, U1.10 (8_TX2_IN1), U1.31 (39_MISO1_OUT1A)
ENA5: SM4.4
GND: C1.2, C2.2, C3.2, C4.2, C5.2, C6.2, C7.2, C8.2, C9.2, C10.2, C11.2, C12.2, C13.2, C14.2, C15.2, C16.2, C17.2, C18.2, C53.2, C54.2, C55.2, PS1.3 (VIN(-)/GND), PS1.4 (VOUT(-)/GND), PS1.32 (SYNC), PS2.3 (VIN(-)/GND), PS2.4 (VOUT(-)/GND), PS2.32 (SYNC), PS3.3 (VIN(-)/GND), PS3.4 (VOUT(-)/GND), PS3.32 (SYNC), Q4.3 (S), Q5.3 (S), Q6.3 (S), Q7.3 (S), Q8.3 (S), Q9.3 (S), Q10.3 (S), Q11.3 (S), R1.1, R4.2, R5.1, R6.2, R8.2, R9.1, R117.1, R119.1, R120.1, R123.1, R124.1, R125.1, R130.1, R131.1, SM1.5, SM1.6, SM1.7, SM1.8, SM2.5, SM2.6, SM2.7, SM2.8, SM3.5, SM3.6, SM3.7, SM3.8, SM4.5, SM4.6, SM4.7, SM4.8, SW1.2, SW2.2, SW5.2
GNDA: PT1.1, PT2.1, PT3.1, PT4.1, PT5.1, PT6.1, PT7.1, PT8.1, R78.2, R79.1, R80.2, R82.1, R83.2, R85.1, R86.2, R88.1, R89.2, R91.1, R92.2, R94.1, R95.2, R97.1, R98.2, R100.1, U1.34 (GND)
GNDD: C19.2, C33.2, C34.2, C35.2, C36.1, C37.2, C38.1, C39.2, C40.2, C42.2, C43.1, C44.1, C45.2, C46.2, C47.2, C49.2, C50.1, C51.1, C52.2, JP1.1 (A), JP2.1 (A), JP3.1 (A), LC1.2, LC1.5, LC2.2, LC2.5, LC3.2, LC3.5, R10.2, R11.1, R12.2, R65.2, R74.2, R75.2, R76.2, R105.1, R109.1, R114.1, TCADC1.1 (GND), TCADC1.3 (GND), TCADC1.5 (GND), TCADC1.6 (GND), TCADC1.7 (GND), TCADC1.9 (GND), TCADC1.10 (GND), TCADC1.13 (GND), TCADC1.17 (GND), TCADC1.18 (GND), TCADC1.21 (GND), TCADC2.1 (GND), TCADC2.3 (GND), TCADC2.5 (GND), TCADC2.6 (GND), TCADC2.7 (GND), TCADC2.9 (GND), TCADC2.10 (GND), TCADC2.13 (GND), TCADC2.17 (GND), TCADC2.18 (GND), TCADC2.21 (GND), TCADC3.1 (GND), TCADC3.3 (GND), TCADC3.5 (GND), TCADC3.6 (GND), TCADC3.7 (GND), TCADC3.9 (GND), TCADC3.10 (GND), TCADC3.13 (GND), TCADC3.17 (GND), TCADC3.18 (GND), TCADC3.21 (GND), TCADC4.1 (GND), TCADC4.3 (GND), TCADC4.5 (GND), TCADC4.6 (GND), TCADC4.7 (GND), TCADC4.9 (GND), TCADC4.10 (GND), TCADC4.13 (GND), TCADC4.17 (GND), TCADC4.18 (GND), TCADC4.21 (GND), TCADC5.1 (GND), TCADC5.3 (GND), TCADC5.5 (GND), TCADC5.6 (GND), TCADC5.7 (GND), TCADC5.9 (GND), TCADC5.10 (GND), TCADC5.13 (GND), TCADC5.17 (GND), TCADC5.18 (GND), TCADC5.21 (GND), TCADC6.1 (GND), TCADC6.3 (GND), TCADC6.5 (GND), TCADC6.6 (GND), TCADC6.7 (GND), TCADC6.9 (GND), TCADC6.10 (GND), TCADC6.13 (GND), TCADC6.17 (GND), TCADC6.18 (GND), TCADC6.21 (GND), TCADC7.1 (GND), TCADC7.3 (GND), TCADC7.5 (GND), TCADC7.6 (GND), TCADC7.7 (GND), TCADC7.9 (GND), TCADC7.10 (GND), TCADC7.13 (GND), TCADC7.17 (GND), TCADC7.18 (GND), TCADC7.21 (GND), TCADC8.1 (GND), TCADC8.3 (GND), TCADC8.5 (GND), TCADC8.6 (GND), TCADC8.7 (GND), TCADC8.9 (GND), TCADC8.10 (GND), TCADC8.13 (GND), TCADC8.17 (GND), TCADC8.18 (GND), TCADC8.21 (GND), TCADC9.1 (GND), TCADC9.3 (GND), TCADC9.5 (GND), TCADC9.6 (GND), TCADC9.7 (GND), TCADC9.9 (GND), TCADC9.10 (GND), TCADC9.13 (GND), TCADC9.17 (GND), TCADC9.18 (GND), TCADC9.21 (GND), TCADC10.1 (GND), TCADC10.3 (GND), TCADC10.5 (GND), TCADC10.6 (GND), TCADC10.7 (GND), TCADC10.9 (GND), TCADC10.10 (GND), TCADC10.13 (GND), TCADC10.17 (GND), TCADC10.18 (GND), TCADC10.21 (GND), TCADC11.1 (GND), TCADC11.3 (GND), TCADC11.5 (GND), TCADC11.6 (GND), TCADC11.7 (GND), TCADC11.9 (GND), TCADC11.10 (GND), TCADC11.13 (GND), TCADC11.17 (GND), TCADC11.18 (GND), TCADC11.21 (GND), TCADC12.1 (GND), TCADC12.3 (GND), TCADC12.5 (GND), TCADC12.6 (GND), TCADC12.7 (GND), TCADC12.9 (GND), TCADC12.10 (GND), TCADC12.13 (GND), TCADC12.16 (ADDR), TCADC12.17 (GND), TCADC12.18 (GND), TCADC12.21 (GND), U1.47 (GND), U2.12 (GND), U3.5 (AGND), U3.14 (XI), U4.5 (AGND), U4.14 (XI), U5.5 (AGND), U5.14 (XI)
GNDPWR: U1.1 (GND)
Imon PS1: C6.1, R2.1
Imon PS2: C10.1, R3.1
Imon PS3: C16.1, R7.1
MP1_SCL1: R17.2, TCADC1.19 (SCL), U2.5 (SC0)
MP1_SCL2: R23.2, TCADC2.19 (SCL), U2.7 (SC1)
MP1_SCL3: R28.2, TCADC3.19 (SCL), U2.9 (SC2)
MP1_SCL4: R33.2, TCADC4.19 (SCL), U2.11 (SC3)
MP1_SCL5: R47.2, TCADC5.19 (SCL), U2.14 (SC4)
MP1_SCL6: R49.2, TCADC6.19 (SCL), U2.16 (SC5)
MP1_SCL7: R51.2, TCADC7.19 (SCL), U2.18 (SC6)
MP1_SCL8: R53.2, TCADC8.19 (SCL), U2.20 (SC7)
MP1_SDA1: R16.1, TCADC1.20 (SDA), U2.4 (SD0)
MP1_SDA2: R22.1, TCADC2.20 (SDA), U2.6 (SD1)
MP1_SDA3: R27.1, TCADC3.20 (SDA), U2.8 (SD2)
MP1_SDA4: R32.1, TCADC4.20 (SDA), U2.10 (SD3)
MP1_SDA5: R46.1, TCADC5.20 (SDA), U2.13 (SD4)
MP1_SDA6: R48.1, TCADC6.20 (SDA), U2.15 (SD5)
MP1_SDA7: R50.1, TCADC7.20 (SDA), U2.17 (SD6)
MP1_SDA8: R52.1, TCADC8.20 (SDA), U2.19 (SD7)
unnamed: C34.1, C35.1, L1.1, LC1.1
unnamed: C39.1, C40.1, L2.1, LC2.1
unnamed: C46.1, C47.1, L3.1, LC3.1
unnamed: D1.2 (A), J2.2, Q4.1 (D)
unnamed: D2.2 (A), J2.4, Q5.1 (D)
unnamed: D3.2 (A), J3.2, Q6.1 (D)
unnamed: D4.2 (A), J3.4, Q7.1 (D)
unnamed: D5.2 (A), J4.2, Q8.1 (D)
unnamed: D6.2 (A), J5.2, Q9.1 (D)
unnamed: D7.2 (A), J4.4, Q10.1 (D)
unnamed: D8.2 (A), J5.4, Q11.1 (D)
unnamed: FB1.2, R14.1
unnamed: FB2.2, R15.2
unnamed: FB3.2, R19.1
unnamed: FB4.2, R20.2
unnamed: FB5.2, R24.1
unnamed: FB6.2, R25.2
unnamed: FB7.2, R29.1
unnamed: FB8.2, R30.2
unnamed: FB9.2, R34.1
unnamed: FB10.2, R35.2
unnamed: FB11.2, R36.1
unnamed: FB12.2, R37.2
unnamed: FB13.2, R38.1
unnamed: FB14.2, R39.2
unnamed: FB15.2, R40.1
unnamed: FB16.2, R41.2
unnamed: FB17.2, R54.1
unnamed: FB18.2, R55.2
unnamed: FB19.2, R56.1
unnamed: FB20.2, R57.2
unnamed: FB21.2, R58.1
unnamed: FB22.2, R59.2
unnamed: FB23.2, R60.1
unnamed: FB24.2, R61.2
unnamed: JP1.2 (B), R101.2, U3.15 (RATE)
unnamed: JP2.2 (B), R110.2, U4.15 (RATE)
unnamed: JP3.2 (B), R115.2, U5.15 (RATE)
unnamed: LC1.3, R102.2
unnamed: LC1.4, R103.1
unnamed: LC2.3, R106.2
unnamed: LC2.4, R107.1
unnamed: LC3.3, R111.2
unnamed: LC3.4, R112.1
unnamed: PS1.34 (CURRENT_MONITOR), R2.2
unnamed: PS1.6 (TRIM), SW4.2 (B)
unnamed: PS1.2 (~ON/OFF), SW1.1
unnamed: PS2.34 (CURRENT_MONITOR), R3.2
unnamed: PS2.6 (TRIM), SW3.2 (B)
unnamed: PS2.2 (~ON/OFF), SW2.1
unnamed: PS3.34 (CURRENT_MONITOR), R7.2
unnamed: PS3.6 (TRIM), SW6.2 (B)
unnamed: PS3.2 (~ON/OFF), SW5.1
unnamed: PT1.2, SW7.5 (B)
unnamed: PT2.2, SW9.5 (B)
unnamed: PT3.2, SW11.5 (B)
unnamed: PT4.2, SW13.5 (B)
unnamed: PT5.2, SW15.5 (B)
unnamed: PT6.2, SW17.5 (B)
unnamed: PT7.2, SW19.5 (B)
unnamed: PT8.2, SW21.5 (B)
unnamed: Q1.2 (B), U3.2 (BASE)
unnamed: L1.2, Q1.1 (C), R104.1, U3.3 (AVDD)
unnamed: Q2.2 (B), U4.2 (BASE)
unnamed: L2.2, Q2.1 (C), R108.1, U4.3 (AVDD)
unnamed: Q3.2 (B), U5.2 (BASE)
unnamed: L3.2, Q3.1 (C), R113.1, U5.3 (AVDD)
unnamed: Q4.2 (G), R116.2
unnamed: Q5.2 (G), R118.1
unnamed: Q6.2 (G), R121.2
unnamed: Q7.2 (G), R122.1
unnamed: Q8.2 (G), R126.2
unnamed: Q9.2 (G), R127.2
unnamed: Q10.2 (G), R128.1
unnamed: Q11.2 (G), R129.1
unnamed: R77.1, SW7.4 (A)
unnamed: R77.2, R78.1, SW7.1 (A)
unnamed: R79.2, SW7.3 (C), SW7.6 (C)
unnamed: R80.1, R81.2, SW9.1 (A)
unnamed: R81.1, SW9.4 (A)
unnamed: R82.2, SW9.3 (C), SW9.6 (C)
unnamed: R83.1, R84.2, SW11.1 (A)
unnamed: R84.1, SW11.4 (A)
unnamed: R85.2, SW11.3 (C), SW11.6 (C)
unnamed: R86.1, R87.2, SW13.1 (A)
unnamed: R87.1, SW13.4 (A)
unnamed: R88.2, SW13.3 (C), SW13.6 (C)
unnamed: R89.1, R90.2, SW15.1 (A)
unnamed: R90.1, SW15.4 (A)
unnamed: R91.2, SW15.3 (C), SW15.6 (C)
unnamed: R92.1, R93.2, SW17.1 (A)
unnamed: R93.1, SW17.4 (A)
unnamed: R94.2, SW17.3 (C), SW17.6 (C)
unnamed: R95.1, R96.2, SW19.1 (A)
unnamed: R96.1, SW19.4 (A)
unnamed: R97.2, SW19.3 (C), SW19.6 (C)
unnamed: R98.1, R99.2, SW21.1 (A)
unnamed: R99.1, SW21.4 (A)
unnamed: R100.2, SW21.3 (C), SW21.6 (C)
unnamed: R4.1, SW3.1 (A)
unnamed: R5.2, SW3.3 (C)
unnamed: R6.1, SW4.1 (A)
unnamed: R1.2, SW4.3 (C)
unnamed: R8.1, SW6.1 (A)
unnamed: R9.2, SW6.3 (C)
unnamed: PT1.3, SW8.2 (B)
unnamed: PT2.3, SW10.2 (B)
unnamed: PT3.3, SW12.2 (B)
unnamed: PT4.3, SW14.2 (B)
unnamed: PT5.3, SW16.2 (B)
unnamed: PT6.3, SW18.2 (B)
unnamed: PT7.3, SW20.2 (B)
unnamed: PT8.3, SW22.2 (B)
unnamed: R18.2, TCADC1.16 (ADDR)
unnamed: C20.1, R14.2, TCADC1.2 (VIN+)
unnamed: C20.2, R15.1, TCADC1.4 (VIN-)
unnamed: R21.2, TCADC2.16 (ADDR)
unnamed: C21.1, R19.2, TCADC2.2 (VIN+)
unnamed: C21.2, R20.1, TCADC2.4 (VIN-)
unnamed: R26.2, TCADC3.16 (ADDR)
unnamed: C22.1, R24.2, TCADC3.2 (VIN+)
unnamed: C22.2, R25.1, TCADC3.4 (VIN-)
unnamed: R31.2, TCADC4.16 (ADDR)
unnamed: C23.1, R29.2, TCADC4.2 (VIN+)
unnamed: C23.2, R30.1, TCADC4.4 (VIN-)
unnamed: R42.2, TCADC5.16 (ADDR)
unnamed: C24.1, R34.2, TCADC5.2 (VIN+)
unnamed: C24.2, R35.1, TCADC5.4 (VIN-)
unnamed: R43.2, TCADC6.16 (ADDR)
unnamed: C25.1, R36.2, TCADC6.2 (VIN+)
unnamed: C25.2, R37.1, TCADC6.4 (VIN-)
unnamed: R44.2, TCADC7.16 (ADDR)
unnamed: C26.1, R38.2, TCADC7.2 (VIN+)
unnamed: C26.2, R39.1, TCADC7.4 (VIN-)
unnamed: R45.2, TCADC8.16 (ADDR)
unnamed: C27.1, R40.2, TCADC8.2 (VIN+)
unnamed: C27.2, R41.1, TCADC8.4 (VIN-)
unnamed: R62.2, R74.1, TCADC9.16 (ADDR)
unnamed: C28.1, R54.2, TCADC9.2 (VIN+)
unnamed: C28.2, R55.1, TCADC9.4 (VIN-)
unnamed: R63.2, R75.1, TCADC10.16 (ADDR)
unnamed: C29.1, R56.2, TCADC10.2 (VIN+)
unnamed: C29.2, R57.1, TCADC10.4 (VIN-)
unnamed: R64.2, R76.1, TCADC11.16 (ADDR)
unnamed: C30.1, R58.2, TCADC11.2 (VIN+)
unnamed: C30.2, R59.1, TCADC11.4 (VIN-)
unnamed: C31.1, R60.2, TCADC12.2 (VIN+)
unnamed: C31.2, R61.1, TCADC12.4 (VIN-)
unnamed: R13.2, U2.3 (*RESET)
unnamed: R10.1, U2.1 (A0)
unnamed: R11.2, U2.2 (A1)
unnamed: R12.1, U2.21 (A2)
unnamed: C32.1, R102.1, U3.8 (INA+)
unnamed: C32.2, R103.2, U3.7 (INA-)
unnamed: C33.1, U3.6 (VBG)
unnamed: C41.1, R106.1, U4.8 (INA+)
unnamed: C41.2, R107.2, U4.7 (INA-)
unnamed: C42.1, U4.6 (VBG)
unnamed: C48.1, R111.1, U5.8 (INA+)
unnamed: C48.2, R112.2, U5.7 (INA-)
unnamed: C49.1, U5.6 (VBG)
PS1 Vout: C4.1, C5.1, C12.1, PS1.7 (SENSE+), PS1.8 (VOUT(+)), SM1.1, SM2.1, SM3.1, SM4.1
PS2 Vout: C11.1, C18.1, C53.1, D1.1 (K), D2.1 (K), D3.1 (K), D4.1 (K), D5.1 (K), D6.1 (K), D7.1 (K), D8.1 (K), J2.1, J2.3, J3.1, J3.3, J4.1, J4.3, J5.1, J5.3, PS2.7 (SENSE+), PS2.8 (VOUT(+))
PS3 Vout: C17.1, C54.1, C55.1, PS3.7 (SENSE+), PS3.8 (VOUT(+))
PT1: SW7.2 (B), U1.45 (23_A9_CRX1_MCLK1)
PT2: SW9.2 (B), U1.44 (22_A8_CTX1)
PT3: SW11.2 (B), U1.43 (21_A7_RX5_BCLK1)
PT4: SW13.2 (B), U1.42 (20_A6_TX5_LRCLK1)
PT5: SW15.2 (B), U1.39 (17_A3_TX4_SDA1)
PT6: SW17.2 (B), U1.38 (16_A2_RX4_SCL1)
PT7: SW19.2 (B), U1.37 (15_A1_RX3_SPDIF_IN)
PT8: SW21.2 (B), U1.36 (14_A0_TX3_SPDIF_OUT)
PUL1: SM1.2, U1.2 (0_RX1_CRX2_CS1)
PUL2: SM2.2, U1.5 (3_LRCLK2)
PUL3: SM3.2, U1.8 (6_OUT1D), U1.33 (41_A17)
PUL4: SM4.2
RELAY: R124.2, R125.2, R126.1, R127.1, R128.2, R129.2, R130.2, R131.2
RELAY1: R116.1, R117.2, U1.17 (25_A11_RX6_SDA2)
RELAY2: R118.2, R119.2, U1.18 (26_A12_MOSI1)
RELAY3: R120.2, R121.1, U1.19 (27_A13_SCK1)
RELAY4: R122.2, R123.2, U1.20 (28_RX7)
RELAY5: U1.21 (29_TX7)
RELAY6: U1.22 (30_CRX3)
RELAY7: U1.23 (31_CTX3)
RELAY8: U1.24 (32_OUT1B)
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

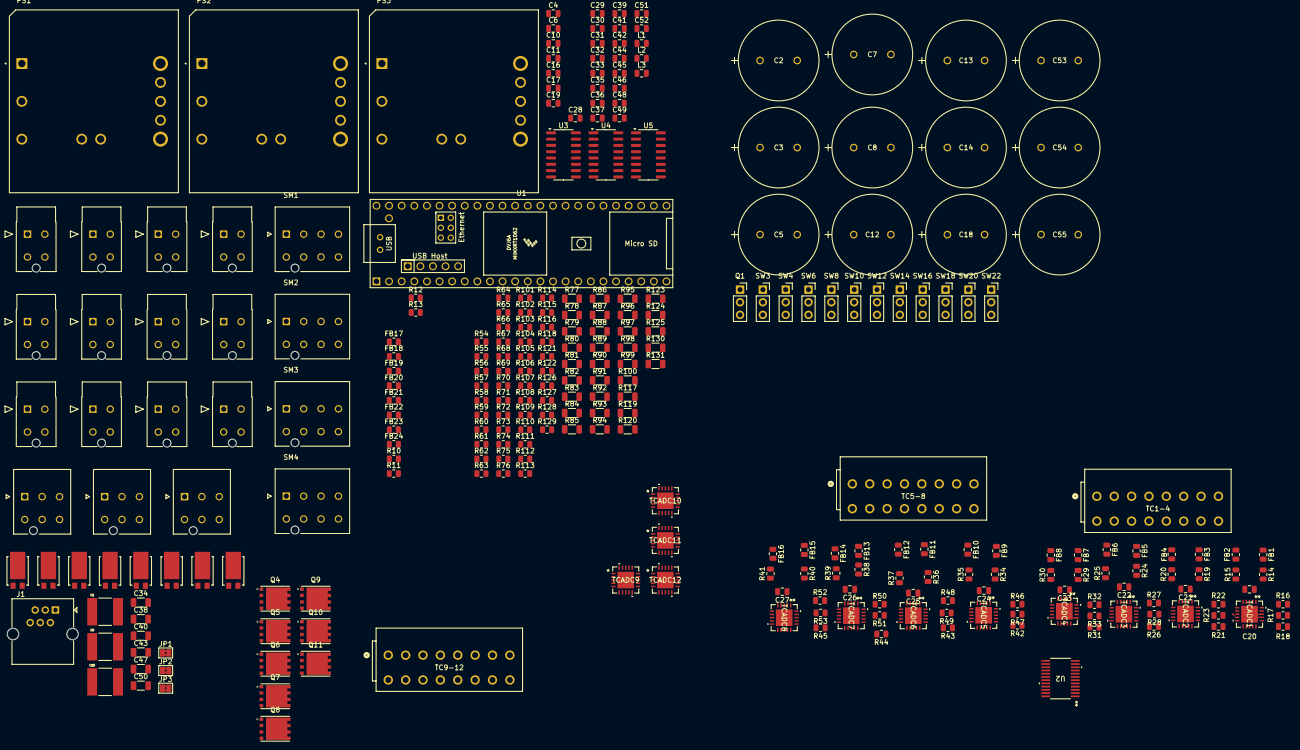
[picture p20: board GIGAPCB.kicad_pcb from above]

Board: 4 copper layers, 278 parts (0 on the bottom side), 198 nets.

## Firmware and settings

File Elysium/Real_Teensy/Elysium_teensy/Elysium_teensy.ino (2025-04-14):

/*
-------------------------------------------------------------------
VARIABLES & USER INPUT
-------------------------------------------------------------------
*/

#include <Arduino.h>

// time variables
long unsigned LAST_SENSOR_UPDATE = 0;                     // Timestamp of last sensor reading (microsec)
const long unsigned SENSOR_UPDATE_INTERVAL = 1000;        // sensor update interval (microsec)              <-- USER INPUT

long unsigned LAST_LC_UPDATE = 0;                         // Timestamp of last Load Cell reading (microsec)
const long unsigned LC_UPDATE_INTERVAL = 100000;          // Load Cell update interval (microsec)           <-- USER INPUT

long unsigned LAST_COMMUNICATION_TIME = 0;                // Timestamp of last communication of any type (microsec)
const long unsigned CONNECTION_TIMEOUT = 200000;          // automated shutdown timeout for complete comms failure (microsec)           <-- USER INPUT

long unsigned LAST_HUMAN_UPDATE = 0;                      // Timestamp of last human communication(microsec)
const long unsigned HUMAN_CONNECTION_TIMEOUT = 300000000; // automated shutdown timeout for human comms failure (microsec)              <-- USER INPUT

long unsigned ABORT_TIME_TRACKING = 0;
const long unsigned ABORTED_TIME_INTERVAL = 500000;       // microsec between printing "aborted" (when aborted)
const long unsigned SHUTDOWN_PURGE_TIME = 2000;           // duration of purge for shutdown, in milliseconds

// BAUD rate 
const int BAUD = 115200;                   // serial com in bits per second     <-- USER INPUT

// LABV 1 state variable
bool is_LABV1_open = false;

/*
VALVE SETUP
*/

// Valves
const int NCS1_PIN = 7;           // <-- USER INPUT
const int NCS2_PIN = 8;           // <-- USER INPUT
const int NCS4_PIN = 11;           // <-- USER INPUT
const int LABV1_PIN = 5;          // <-- USER INPUT
const int LABV2_PIN = 6;          // <-- USER INPUT

// Igniter
const int IGN1_PIN = 10;          // <-- USER INPUT
const int IGN2_PIN = 9;          // <-- USER INPUT

// serial input variables
String IDENTIFIER = "";
int CONTROL_STATE = 0;

// Function to get pin number from string
int get_pin(String id) {
  if (id == "NCS1") {
    return NCS1_PIN;
  } else if (id =="NCS2") {
    return NCS2_PIN;
  } else if (id =="NCS4") {
    return NCS4_PIN;
  } else if (id =="LA-BV1") {
    return LABV1_PIN;
  } else if (id =="LA-BV2") {
    return LABV2_PIN;
  } else if (id =="IG1") {
    return IGN1_PIN;
  } else if (id =="IG2") {
    return IGN2_PIN;
  }

  // Return -1 if no match was found
  return -1;
}

#include <NativeEthernet.h>
#include <NativeEthernetUdp.h>
#include <IPAddress.h>

unsigned int PORT = 8888;
char packetBuffer[UDP_TX_PACKET_MAX_SIZE];  // buffer to hold incoming packet,
// An EthernetUDP instance to let us send and receive packets over UDP
EthernetUDP udp;
byte MAC_ADDRESS[] = {0xDE, 0xAD, 0xBE, 0xEF, 0xFE, 0xED};
IPAddress REMOTE(192, 168, 1, 175);
IPAddress LOCAL(192, 168, 1, 174);

void output_string(unsigned int port, const char *to_write) {
  udp.beginPacket(REMOTE, port);
  udp.write(to_write);
  udp.endPacket();
}

void output_float(unsigned int port, float to_write) {
  char buf[100]; // *slaps roof* yeah that'll do nicely
  constexpr unsigned long PRECISION = 5;
  dtostrf(to_write, 1, PRECISION, buf);
  udp.beginPacket(REMOTE, port);
  udp.write(buf);
  udp.endPacket();
}

String input_until(char stop_character) {
  String ret = "";
  char c = udp.read();
  while (c != stop_character) {
    ret += c;
    c = udp.read();
  }
  return ret;
}

bool init_comms(byte* mac, unsigned int port) {
  EthernetUDP ret;
  IPAddress GATEWAY(192, 168, 1, 1);   // there is no router, so this is meaningless 
  IPAddress SUBNET(255, 255, 255, 0);  // could be almost anything else tbh
  Ethernet.begin(mac, LOCAL, GATEWAY, SUBNET);
  if (Ethernet.hardwareStatus() == EthernetNoHardware) {
    Serial.println("ERR: No Ethernet board detected");
    return false;
  } else if (Ethernet.linkStatus() == LinkOFF) {
    Serial.println("ERR: Ethernet cable disconnected");
    return false;
  }
  udp.begin(port);
  return true;
}

/*
LOAD CELL SET UP
----------------
*/

// import library
#include "HX711.h"

// define data and clock pins for each loadcell
const int LC1_D_OUT_PIN = 28;            // <-- USER INPUT
const int LC1_CLK_PIN = 29;              // <-- USER INPUT
const int LC2_D_OUT_PIN2 = 26;           // <-- USER INPUT
const int LC2_CLK_PIN2 = 27;             // <-- USER INPUT
const int LC3_D_OUT_PIN3 = 24;           // <-- USER INPUT
const int LC3_CLK_PIN3 = 25;             // <-- USER INPUT

// measurement set up
float weight1 = 0;
float weight2 = 0;
float weight3 = 0;
HX711 scale, scale2, scale3;



/*
THERMOCOUPLE SET UP
----------------
*/

// Thermocouple libraries
#include <Wire.h>
#include <Adafruit_I2CDevice.h>
#include <Adafruit_I2CRegister.h>
#include <Adafruit_MCP9600.h>

// Thermocouple I2C addresses
#define I2C_ADDRESS1 (0x67)
//#define I2C_ADDRESS2 (0x66)

// Thermocouple mcp identifier
Adafruit_MCP9600 mcp;
//Adafruit_MCP9600 mcp2;


/*
PRESSURE TRANSDUCER SET UP
--------------------------------
*/

// teensy pins to read signals
const int PT1_PIN = 23;                    // <-- USER INPUT
const int PT2_PIN = 22;                    // <-- USER INPUT
const int PT3_PIN = 21;                    // <-- USER INPUT
const int PT4_PIN = 20;                    // <-- USER INPUT
const int PT5_PIN = 17;                    // <-- USER INPUT
const int PT6_PIN = 16;                    // <-- USER INPUT
 

// analog and digital reading variables setup
int pt1_analog = 0;                        // analog reading from PT output signal
int pt2_analog = 0;                        // analog reading from PT output signal
int pt3_analog = 0;                        // analog reading from PT output signal
int pt4_analog = 0;                        // analog reading from PT output signal
int pt5_analog = 0;                        // analog reading from PT output signal
int pt6_analog = 0;                        // analog reading from PT output signal

// Calibration constants
const float pt_slope[] = {1.22983871, 1.22983871, 1.22983871, 1.22983871, 1.22983871, 1.22983871};
const float pt_intercept[] = {-111.9733871, -105.8241935, -109.5137097, -111.9733871, -108.283871, -113.2032258};

// Calibration constants for pure analog readings
//const float pt_slope[] = {1, 1, 1, 1, 1, 1};
//const float pt_intercept[] = {0, 0, 0, 0, 0, 0};

// Function to calculate pressure
float pressureCalculation(float analog, size_t id) {
    // Calculate pressure based on analog input
    return pt_slope[id-1] * analog + pt_intercept[id-1];
}

/*
ACCELEROMETER SET UP
----------------
*/

// import libraries
#include "IMU.h"
#include "LSM6DSL.h"
#include "LIS3MDL.h"

// measurement variable setup
byte buff[6];
int accRaw[3];
float accx, accy, accz;
const float accoffset = 4180;

/*
-------------------------------------------------------------------
SETUP LOOP
-------------------------------------------------------------------
*/
void setup() {
  // Serial.begin(BAUD);           // initializes serial communication at set baud rate
  init_comms(MAC_ADDRESS, PORT);  // does what it says on the tin
  Wire.begin();

  /*
  VALVE SET UP
  -----------------------
  */
  output_string(PORT, "test1");
  // Serial.println("test1");

  pinMode(NCS1_PIN, OUTPUT);    // sets the digital pin as output for controlling Valve 1 MOSFET
  pinMode(NCS2_PIN, OUTPUT);    // sets the digital pin as output for controlling Valve 2 MOSFET
  pinMode(NCS4_PIN, OUTPUT);    // sets the digital pin as output for controlling Valve 4 MOSFET
  pinMode(LABV1_PIN, OUTPUT);    // sets the digital pin as output for controlling Valve 5 MOSFET
  pinMode(LABV2_PIN, OUTPUT);    // sets the digital pin as output for controlling Valve 6 MOSFET
  pinMode(IGN1_PIN, OUTPUT);
  pinMode(IGN2_PIN, OUTPUT);

  // Serial.println("test2_Pins");
  output_string(PORT, "test2_Pins");

  /*
  THERMOCOUPLE SET UP
  -----------------------
  */

  // Initialize MCP9600 sensors
  mcp.begin(I2C_ADDRESS1);
  //mcp2.begin(I2C_ADDRESS2);

  // Configure both sensors
  mcp.setADCresolution(MCP9600_ADCRESOLUTION_18);
  mcp.setThermocoupleType(MCP9600_TYPE_K);
  mcp.setFilterCoefficient(3);
  mcp.enable(true);

  //mcp2.setADCresolution(MCP9600_ADCRESOLUTION_18);
  //mcp2.setThermocoupleType(MCP9600_TYPE_K);
  //mcp2.setFilterCoefficient(3);
  //mcp2.enable(true);

  // Serial.println("test3_TC");
  output_string(PORT, "test3_TC");

  /*
  LOAD CELL SET UP
  -----------------------
  */

  // load cell setup
  scale.begin(LC1_D_OUT_PIN, LC1_CLK_PIN);
  scale2.begin(LC2_D_OUT_PIN2, LC2_CLK_PIN2);
  scale3.begin(LC3_D_OUT_PIN3, LC3_CLK_PIN3);

  // scale and tare load cells
  scale.set_scale(-3980.f);  // Set the scale factor for conversion to pounds
  scale.tare();             // Reset the scale to zero

  scale2.set_scale(-3880.f); // Set the scale factor for conversion to pounds
  scale2.tare();            // Reset the scale to zero

  scale3.set_scale(-3780.f); // Set the scale factor for conversion to pounds
  scale3.tare();            // Reset the scale to zero
  
  // Serial.println("test4_LC");
  output_string(PORT, "test4_LC");
  /*
  ACCELEROMETER SET UP
  -----------------------
  */

  // detect and enable IMU
  // detectIMU();
  // enableIMU();
}

/*
-------------------------------------------------------------------
LOOP
-------------------------------------------------------------------
*/
void loop() {
  // checks if user input is available to read
  udp.parsePacket();
  if (udp.available() > 0) {
    // read communication
    String input = input_until('\n');
    LAST_COMMUNICATION_TIME = micros();

    // no operation command to confirm connection
    if (input != "nop\r") {
      LAST_HUMAN_UPDATE = micros();
    } else {
      return;
    }

    // break string into identifier and control state
    int delimiterIndex = input.indexOf(':');
    if (delimiterIndex != -1) {
      IDENTIFIER = input.substring(0, delimiterIndex);
      CONTROL_STATE = input.substring(delimiterIndex + 1).toInt();
    }
    else { return; }

    int pin = get_pin(IDENTIFIER);
    if (pin == -1) {
      return;
    }
    switch (CONTROL_STATE) {
      case 0:
        digitalWrite(pin, LOW);   // Close Valve
        if (IDENTIFIER == "LA-BV1") {
          if (is_LABV1_open) {
            digitalWrite(NCS2_PIN, HIGH);
          }
          is_LABV1_open = false;
        }
        break;
      case 1:
        digitalWrite(pin, HIGH);  // Open Valve
        if (IDENTIFIER == "LA-BV1") {
          is_LABV1_open = true;
        }
        break;
    }
  }

  // check for last reading update
  if ((micros() - LAST_SENSOR_UPDATE) > SENSOR_UPDATE_INTERVAL) {
    LAST_SENSOR_UPDATE = micros();                               // update time

    // read pressure data
    pt1_analog = analogRead(PT1_PIN);                          // reads value from input pin and assigns to variable
    pt2_analog = analogRead(PT2_PIN);                          // reads value from input pin and assigns to variable.
    pt3_analog = analogRead(PT3_PIN);
    pt4_analog = analogRead(PT4_PIN);
    pt5_analog = analogRead(PT5_PIN);
    pt6_analog = analogRead(PT6_PIN);

    // read acceleration
    // readACC(buff);
    // accRaw[0] = (int16_t)(buff[0] | (buff[1] << 8)); 
    // accRaw[1] = (int16_t)(buff[2] | (buff[3] << 8));
    // accRaw[2] = (int16_t)(buff[4] | (buff[5] << 8));
    // accx = accRaw[0]/accoffset;
    // accy = accRaw[1]/accoffset;
    // accz = accRaw[2]/accoffset;

    // measure force from load cells, only update at slower interval
    if ((LAST_SENSOR_UPDATE - LAST_LC_UPDATE) > LC_UPDATE_INTERVAL) {
      LAST_LC_UPDATE = LAST_SENSOR_UPDATE;
      weight1 = scale.get_units(1);  // Get the weight in lbs
      weight2 = scale2.get_units(1); // Get the weight in lbs
      weight3 = scale3.get_units(1); // Get the weight in lbs
    }

    // measure temp from thermocouples in °C
    float t1 = mcp.readThermocouple();
    
    // send data to serial monitor
    output_string(PORT, "t:");
    output_float(PORT, LAST_SENSOR_UPDATE);
    output_string(PORT, ",P1:");
    output_float(PORT, pressureCalculation(pt1_analog, 1));
    output_string(PORT, ",P2:");
    output_float(PORT, pressureCalculation(pt2_analog, 2));
    output_string(PORT, ",P3:");
    output_float(PORT, pressureCalculation(pt3_analog, 3));
    output_string(PORT, ",P4:");
    output_float(PORT, pressureCalculation(pt4_analog, 4));
    output_string(PORT, ",P5:");
    output_float(PORT, pressureCalculation(pt5_analog, 5));
    output_string(PORT, ",P6:");
    output_float(PORT, pressureCalculation(pt6_analog, 6));
    output_string(PORT, ",T1:");
    output_float(PORT, t1);
    output_string(PORT, ",L1:");
    output_float(PORT, weight1);
    output_string(PORT, ",L2:");
    output_float(PORT, weight2);
    output_string(PORT, ",L3:");
    output_float(PORT, weight3);
    output_string(PORT, ",t_loc:");
    float t_loc = (HUMAN_CONNECTION_TIMEOUT - (LAST_SENSOR_UPDATE -LAST_HUMAN_UPDATE)) / 1000000.0;
    output_float(PORT, t_loc);
    output_string(PORT, "\n");
    delay(10);
    // Serial.print("t:"); Serial.print(LAST_SENSOR_UPDATE);                             // print time reading in microseconds
    // Serial.print(",P1:"); Serial.print(pressureCalculation(pt1_analog, 1));           // print pressure calculation in psi
    // Serial.print(",P2:"); Serial.print(pressureCalculation(pt2_analog, 2));           // print pressure calculation in psi
    // Serial.print(",P3:"); Serial.print(pressureCalculation(pt3_analog, 3));           // print pressure calculation in psi
    // Serial.print(",P4:"); Serial.print(pressureCalculation(pt4_analog, 4));           // print pressure calculation in psi
    // Serial.print(",P5:"); Serial.print(pressureCalculation(pt5_analog, 5));           // print pressure calculation in psi
    // Serial.print(",P6:"); Serial.print(pressureCalculation(pt6_analog, 6));           // print pressure calculation in psi

    // Serial.print(",T1:"); Serial.print(t1);                                           // print thermocouple temperature in C
    // // Serial.print(",T2:"); Serial.print(mcp2.readThermocouple());                   // print thermocouple temperature in C
    // Serial.print(",L1:"); Serial.print(weight1);                                      // print load cell 1 in lbs
    // Serial.print(",L2:"); Serial.print(weight2);                                      // print load cell 2 in lbs
    // Serial.print(",L3:"); Serial.print(weight3);                                      // print load cell 3 in lbs
    // // Serial.print(",Ax:"); Serial.print(accx);                                      // print acceleration in x direction  <-- determine what direction x is in relation to engine
    // // Serial.print(",Ay:"); Serial.print(accy);                                      // print acceleration in y direction  <-- determine what direction y is in relation to engine
    // // Serial.print(",Az:"); Serial.print(accz);                                      // print acceleration in z direction  <-- determine what direction z is in relation to engine
    // float t_loc = (HUMAN_CONNECTION_TIMEOUT - (LAST_SENSOR_UPDATE -LAST_HUMAN_UPDATE)) / 1000000.0;
    // Serial.print(",t_loc:"); Serial.println(t_loc);                                     // print time until loss of communications occurs, in seconds (only due to human inaction)
    //Serial.println();
    //delay(10);
  }

  // Lost communication shutdown
  if (((micros() - LAST_COMMUNICATION_TIME) > CONNECTION_TIMEOUT) || ((micros() - LAST_HUMAN_UPDATE) > HUMAN_CONNECTION_TIMEOUT)) {
    // Open NCS2
    digitalWrite(NCS2_PIN, HIGH);

    // Close ball valves & NCS1
    digitalWrite(NCS1_PIN, LOW);
    digitalWrite(NCS4_PIN, LOW);
    digitalWrite(LABV1_PIN, LOW);
    digitalWrite(LABV2_PIN, LOW);

    // Unpower igniters
    digitalWrite(IGN1_PIN, LOW);
    digitalWrite(IGN2_PIN, LOW);

    // If LABV1 is open, system purges with nitrogen
    if (is_LABV1_open) {
      // Open NCS4 for 3 seconds
      digitalWrite(NCS4_PIN, HIGH);
      delay(SHUTDOWN_PURGE_TIME);
      digitalWrite(NCS4_PIN, LOW);
    }

    // While system is aborted, print "aborted" until a start command is received
    bool aborted = true;
    while(aborted) {
      if ((micros() - ABORT_TIME_TRACKING) > ABORTED_TIME_INTERVAL) {
        ABORT_TIME_TRACKING = micros();
        output_string(PORT, "Aborted\n");
        // Serial.println("Aborted");
      }

      udp.parsePacket();
      if (udp.available() > 0) {
        // String input = Serial.readStringUntil('\n');
        String input = input_until('\n');
        output_string(PORT, ("New Input= " + input + '\n').c_str());
        // Serial.println("New Input= " + input);

        if ((input == "start\r") || (input == "Start\r")){
          aborted = false;
          LAST_COMMUNICATION_TIME = micros();
          LAST_HUMAN_UPDATE = micros();
          digitalWrite(NCS2_PIN, LOW);
        }
      }
    }
  }
}

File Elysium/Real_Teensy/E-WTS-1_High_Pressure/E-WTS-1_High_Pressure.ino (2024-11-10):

/*
-------------------------------------------------------------------
TIME AND COMMUNICATION SETUP
-------------------------------------------------------------------
*/

// time variables
long unsigned sensor_update_last = 0;
long unsigned connection_last = 0;
const long unsigned SENSOR_UPDATE_INTERVAL = 100;       // Time between remeasuring sensors (microsec)               <-- USER INPUT
const long unsigned CONNECTION_TIMEOUT = 200000;      // Time without comms before automated shutdown (microsec)   <-- USER INPUT
const long unsigned TIMEOUT_PRINT_INTERVAL = 500000;  // Time betweeen alerts when comms are out (microsec)        <-- USER INPUT

// BAUD rate 
const int BAUD = 115200;    // serial com in bits per second     <-- USER INPUT

/*
-------------------------------------------------------------------
VALVE & IGNITER SETUP
-------------------------------------------------------------------
*/

// Valve pins
const int NCS1_PIN = 7;           // <-- USER INPUT
const int NCS2_PIN = 10;          // <-- USER INPUT
const int NCS4_PIN = 9;          // <-- USER INPUT
const int LABV1_PIN = 5;          // <-- USER INPUT

// Igniter pins
const int IG1_PIN = 11;           // <-- USER INPUT
const int IG2_PIN = 12;           // <-- USER INPUT

// Function to get pin number from string
int get_pin(String id) {
  if (id == "NCS1") {
    return NCS1_PIN;
  } else if (id =="NCS2") {
    return NCS2_PIN;
  } else if (id =="NCS4") {
    return NCS4_PIN;
  } else if (id =="LA-BV1") {
    return LABV1_PIN;
  } else if (id == "IGNITE") {
    return IG1_PIN;
  }

  // Return -1 if no match was found
  return -1;
}

/*
-------------------------------------------------------------------
PRESSURE TRANSDUCER SET UP
-------------------------------------------------------------------
*/

// teensy pins to read signals
const int PT1_PIN = 15;                    // <-- USER INPUT
const int PT2_PIN = 16;                    // <-- USER INPUT

int pt1_analog = 0;                        // analog reading from PT output signal
int pt2_analog = 0;                        // analog reading from PT output signal

// Calibration constants
const float PT_SLOPES[] = {0.927016, 0.927016};     // <-- USER INPUT
const float PT_INTERCEPTS[] = {-68.75, -68.75};     // <-- USER INPUT

// Function to calculate pressure
float get_pressure(float analog_reading, size_t id) {
  // Convert Voltage reading to measurement in psi with the correct calibration factors
  // PTs are 1-indexed, the lists are 0-indexed
  return PT_SLOPES[id-1] * analog_reading + PT_INTERCEPTS[id-1];
}


void setup() {
  // Initialize serial communication as configured and start thermocouple library
  Serial.begin(BAUD);

  // VALVES & IGNITERS
  // Configure digital pins for actuating valves and igniteres as output only
  pinMode(NCS1_PIN, OUTPUT);
  pinMode(NCS2_PIN, OUTPUT);
  pinMode(NCS4_PIN, OUTPUT);
  pinMode(LABV1_PIN, OUTPUT);
}

void loop() {
  /*
  -------------------------------------------------------------------
  SENSOR READING
  -------------------------------------------------------------------
  */

  // Check how long it has been since the last measurement
  if ((micros() - sensor_update_last) > SENSOR_UPDATE_INTERVAL) {
    // Update the time of last reading
    sensor_update_last = micros();

    // Read Pressure Transducer analog data
    pt1_analog = analogRead(PT1_PIN);
    pt2_analog = analogRead(PT2_PIN);

    // Print sensor readings to the serial output
    // Convert pressures to psi
    Serial.print("P1:"); Serial.print(get_pressure(pt1_analog, 1));
    Serial.print(",P2:"); Serial.print(get_pressure(pt2_analog, 2));

    // End the line to signify the end of message
    Serial.println();
  }

  /*
  -------------------------------------------------------------------
  VALVE & IGNITER ACTUATION
  -------------------------------------------------------------------
  */

  if (Serial.available() > 0) {
    // Update the time since last communication
    connection_last = micros();

    // read communication until end of message
    String input = Serial.readStringUntil('\n');

    // nop is the no operation command, which is merely to confirm that the connection is active
    if (input == "nop\r") { return; }

    // Parse message into ID and value, convert to pin number and an int
    // If message cannot be split, it is meaningless
    int split_index = input.indexOf(':');
    if (-1 == split_index) { return; }

    // If the pin number cannot be resolved, it is meaningless
    int pin = get_pin(input.substring(0, split_index));
    if (-1 == pin) { return; }

    // Convert the second half of the string to the integer value
    int value = input.substring(split_index + 1).toInt();
  

    // Use the pin and value to actuate the specified valve
    switch (value) {
      case 0:
        digitalWrite(pin, LOW);   // Close Valve, Unpower Igniter

        // Two igniters from the same signal
        if (IG1_PIN == pin) {
          digitalWrite(IG2_PIN, LOW);
        }
        break;
      case 1:
        digitalWrite(pin, HIGH);  // Open Valve, Power Igniter

        // Two igniters from the same signal
        if (IG1_PIN == pin) {
          digitalWrite(IG2_PIN, HIGH);
        }
    }
  }

  /*
  -------------------------------------------------------------------
  COMMUNICATIONS LOSS CHECK
  -------------------------------------------------------------------
  */
  // Check if the time since last communication exceeds the allowable timeout
  if ((micros() - connection_last) > CONNECTION_TIMEOUT) {
    // Guarantee a return to a safe state by Opening NCS2
    digitalWrite(NCS2_PIN, HIGH);
    
    // And then closing all other valves, unpowering igniters
    digitalWrite(NCS1_PIN, LOW);
    digitalWrite(NCS4_PIN, LOW);
    digitalWrite(LABV1_PIN, LOW);
    digitalWrite(IG1_PIN, LOW);
    digitalWrite(IG2_PIN, LOW);

    // Enter a fixed loop until connection is reestablished and reinitiated
    bool connection_lost = true;
    long unsigned print_last = 0;
    while (connection_lost) {
      // Every TIMEOUT_PRINT_INTERAVAL, output the aborted message to alert the operator of the current state
      if ((micros() - print_last) > TIMEOUT_PRINT_INTERVAL) {
        print_last = micros();
        Serial.println("Aborted");
      }

      // Check for input from the operator
      if (Serial.available() > 0) {
        String input = Serial.readStringUntil('\n');
        Serial.println("New Input= " + input);

        // Only respond if the specific string is encountered
        if (input == "Start\r") {
          // Update timer
          connection_last = micros();

          // Exit the connection_lost loop
          connection_lost = false;
        }
      }
    }
  }
}

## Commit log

2024-06-15 All Files
    upload all current code files
2024-06-28 Add comments and fix title captitalization
    [GUI_Architecture.py]
2024-07-10 Removed old comments and print statements
2024-07-15 Remove test statements and print statements
2024-07-15 Added base/frames for DAQ and CTRL classes
2024-07-18 Implemented simple Virtual Teensy, updated COM and documentation
2024-07-19 Implemented valve classes and framework for sensors
2024-07-23 Added core components and visual check for Sensor class
2024-07-23 Fixed margins on Valves and Sensors
    [Valves.cpp]
2024-07-24 Implemented new data format for Virtual Teensy
2024-07-24 Implemented configuration file system
    [main.cfg, sensors.cfg, valves.cfg]
2024-07-25 Added documentation for configuration files, fixed typo in valve header
2024-07-25 Implemented live updating sensors
    [sensors.cfg]
2024-07-28 Implemented dark theme, updated general visuals
    [dark.cfg]
2024-07-31 Implemented file buttons, creation, and headers for CTRL and DAQ data
    [main.cfg]
2024-07-31 Implemented data saving for valves (no control states)
2024-08-01 Implemented sensor writing to file (no local time yet)
2024-08-01 Updated themes
    [dark.cfg, light.cfg]
2024-08-02 Implemented control state display and saving
    [control_states.cfg]
2024-08-13 Added (terminal) alert for Teensy disconnect, sped up virtual teensy
2024-08-25 Updated Valve and Sensors configs for hotfire
    [sensors.cfg, valves.cfg]
2024-09-01 Updated serial port info printing/checking
2024-09-02 Added Virtual Teensy Framework
    [main.cfg]
2024-09-02 Added correct write outputs
    [hotfire_1.cfg]
2024-09-02 Added ability to add/remove sensors + store last configuration
    [hotfire_1.cfg]
2024-09-03 Fixed typo in valve name
    [valves.cfg]
2024-09-03 Added WTS Teensy program
2024-09-11 Added ethernet test code (broken)
    [Ethernet_Teensy.ino]
2024-09-12 Added base header for state machine control
    [water_test_1.cfg]
2024-09-13 Create Teensy_Code
2024-09-16 Added general/Elysium documentation
    [main.cfg]
2024-09-16 Updated Jet-A to Fuel, to be more accurate
    [sensors.cfg]
2024-09-16 Aligned Save Buttons
2024-09-16 Updated Jet-A to fuel
    [valves.cfg]
2024-09-16 Updated Elysium Control States and display
    [control_states.cfg, dark.cfg]
2024-09-19 uploaded teensy code
2024-09-19 Added teensy code
2024-09-21 Added PT calibration DAQ code
2024-09-29 Attached State Machine, updated config, not fully implemented
    [control_states.cfg]
2024-09-29 Updated Control States
    [control_states.cfg]
2024-09-30 Implemented Control States (some features missing)
    [Valves.cpp]
2024-10-01 Added load cell calibration sketch
2024-10-03 added elysium teensy libraries
2024-10-03 Added sample rate calculation
2024-10-08 Added safety and abort buttons, updated visuals
    [dark.cfg, light.cfg]
2024-10-13 Added Igniter Test code
    [control_states.cfg, sensors.cfg, valves.cfg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]
2024-10-13 Fixed Teensy code for ignition test
2024-10-16 README for teensy code added
2024-10-16 updated WTS teensy code
2024-10-24 updated WTS & Teensy code
2024-10-24 updated Teensy code
2024-10-25 Updated new WTS Teensy code
2024-11-01 Updated Load Cell Calibration Program
2024-11-03 Added E-WTS-1 Configurations
    [control_states.cfg, main.cfg, sensors.cfg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]
2024-11-07 Changed valve name in config
    [main.cfg, valves.cfg]
2024-11-07 Reorganized WTS and Teensy Code
2024-11-07 Updated Elysium WTS 1 Teensy code
2024-11-07 Added nop to GUI, corrected in E-WTS-1 Teensy programs
    [main.cfg]
2024-11-08 Fixed Connection Timeout failsafe
    [valves.cfg]
2024-11-09 Updated calibration constants
2024-11-10 Updated Pin Numbers
    [main.cfg, valves.cfg]
2024-11-14 Updated Accelerometer name
2024-11-15 added test configs and updated ids in hotfire
    [control_states.cfg, main.cfg, sensors.cfg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]
2024-11-19 updated Elysium Teensy code
2024-11-22 Updated Fire Sequence
    [control_states.cfg, dark.cfg, light.cfg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]
2024-11-23 Added auto-abort capabilities
    [hotfire_1.cfg, main.cfg, sensors.cfg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]
2024-12-01 Removed tedious prints for debugging
2024-12-01 Fixed minor visual bug with overlapping buttons
    [control_states.cfg]
2024-12-03 Improved Teensy sensor refresh rate + command conflict
    [sensors.cfg]
2024-12-06 Fixed Timer's precision and misplaced delimiter
2025-01-14 Updated hotfire timing and ignition procedure for 1.1 fire
    [control_states.cfg]
2025-02-18 Added GIGAPCB files
    [BJT_SMMBT4403LT1G.step, CONN_1722981104_Universal.step, CONN_1722981108_Universal.stp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]
2025-02-25 Uploaded thermocouple calibration code
2025-03-27 virt teensy2
    [hotfire_1.cfg, main.cfg]
2025-04-08 Auto aborts e1.1 v1.0 (#1)
    * Switched over to Ethernet comms
    * Updated Pin numbers
    * Updated auto-abort conditions, timings
    ---------
    [main-LAPTOP-A93BNMFG.cfg]
2025-04-08 Ethernet comms 1.1 (#2)
    * gah
    * Added null terminator
    * Update packet splitting
    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
    [Generic 2106 Capacitor-LAPTOP-A93BNMFG.step]
2025-04-09 Changed fire sequence and aborts
    [control_states.cfg]
2025-04-14 Fixed accidental overwrite commit (#3)
    [Elysium_teensy.ino]

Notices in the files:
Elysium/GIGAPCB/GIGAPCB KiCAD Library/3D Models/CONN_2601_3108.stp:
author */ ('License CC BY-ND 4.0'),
